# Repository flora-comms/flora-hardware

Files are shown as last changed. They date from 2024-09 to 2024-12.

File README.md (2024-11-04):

# flora-hardware

Repository for Petal Radio development.

## Root File Tree Overview

Overview of the root filetree.

### orders

Information related to hardware orders

### resources

Hardware resources, such as datasheets and diagrams.

### petal-v0_0

Hardware design files and assembly notes for Petal Radio V0.0.

### testing

Information related to hardware testing, including test code, checklists, and procedures.

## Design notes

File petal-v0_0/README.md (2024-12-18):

# petal-v0_0

Design, assembly, and testing files for Petal Radio v0.0

## File Tree Overview

Navigating this directory

### assembly

Assembly notes for Petal Radio v0.0. Includes notes on smt and th components, as well as the assembly checklist.

### enclosure

Enclosure files (.step, .stl, etc.)

### testing-results

Petal Radio v0.0 testing results. Testing procedures and templates can be found in the root testing folder.

### pcb

PCB Schematic and Altium files.

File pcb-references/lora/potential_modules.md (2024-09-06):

# Potential LoRa Modules

## WAVE

https://www.waveshare.com/wiki/Core1262-868M#Document

Vendors:
https://abra-electronics.com/wireless/lora/wave-20855.html

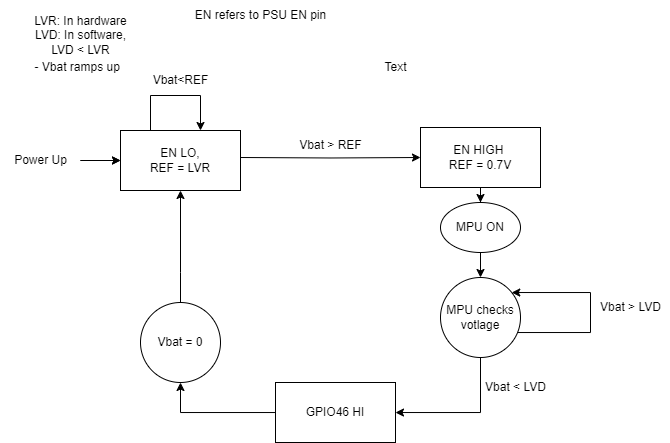
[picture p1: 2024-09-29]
pcb-references/power/LVD-state-machine.drawio.png

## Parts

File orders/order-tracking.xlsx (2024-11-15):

Project Supplies
Order # | Cost | Description | Date Submitted | Revision Date (?) | Date Approved | Received | Notes
1 | $108.85 | Wave LoRa Modules x 6 | 2024-09-16 | 2024-09-17 | 2024-09-17
2 | $22.15 | Jumpers and Justin's hogs x 2 | 2024-09-23 | n/a | 2024-09-23
3 | $210.07 | Petal v0.0 hardware order | 2024-10-14 | 2024-10-15 | 2024-10-15 | Friday,Octoder 18, 2024 | 47uF caps and 1k5 res were out of stock @ mouser, switched to kyocera caps and found res in stock on digikey
4 | $61.07 | Spare petal hardware and sd cards. Mouser + Amazon | 2024-11-04 | n/a | 2024-11-05 | Friday, October 8 and Tuesday October 12 | Amazon order came later than mouser
5 | $21.37 | IPEX to N and N to SMA RF connectors | 2024-11-11 | n/a | 2024-11-13 |  | Delayed… pushed back testing a week
 |  |  |  | n/a
 |  |  |  | n/a
 |  |  |  | n/a
PCB
Order # | Estimated Cost | Description | Date Submitted | Revision Date (?) | Date Approved | Notes
1 | $50.00 | Petal Radio v0.0 x 5 | 2024-10-14 | n/a | 2024-10-15 | JLC was unsure about the footprints for J8 and J7 because of the large solder mask opening. Told them to continue per the gerber -AH
 |  |  |  | n/a
 |  |  |  | n/a
 |  |  |  | n/a
 |  |  |  | n/a
 |  |  |  | n/a
 |  |  |  | n/a
 |  |  |  | n/a

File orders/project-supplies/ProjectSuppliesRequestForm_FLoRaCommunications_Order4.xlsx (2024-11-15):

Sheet: Mouser
 | Project Course Purchase Request Form. Post this to the #prep-room_orders channel when complete.
 | Project Name: |  |  | FLoRa Communications |  | Preferred Vendor: | Mouser | Student Name: | Aaron Huinink
 | Date: |  |  | 2024-11-15 |  |  |  | Student Email: | ahuinink@hotmail.ca
 |  |  |  |  |  |  | PLEASE FILL OUT ONE FORM PER PREFERRED VENDOR
 |  |  |  |  |  |  |  |  |  |  | FOR OFFICE USE ONLY
No. | Qty | QTY Rec. | Manufacturer Part # | Vendor Part # | Link to Part (URL) | Shipping From ( Country ) | Detailed Part Description | PCB Footprint | Unit Price ($CDN) | Extended Price | Notes for Office | Ordered | Delivered
1 | 20 |  | GCM21BR72A104KA37L | 81-GCM21BR72A104KA7L | https://www.mouser.ca/ProductDetail/Murata-Electronics/GCM21BR72A104KA37L?qs=aEuGZpxfbxU57i7kalIPTw%3D%3D | Canada | 100 nF Ceramic Capacitor - C1, C7, C8, C9, C12 (*C5&C6 removed from board) | 0805 | 0.113 | $2.2600
2 | 10 |  | GRM21BR60J226ME39L | 81-GRM21R60J226ME39L | https://www.mouser.ca/ProductDetail/Murata-Electronics/GRM21BR60J226ME39L?qs=DJY02EClX9n4vY1%2FNV53Qw%3D%3D | Canada | 22uF Ceramic Capacitor - C2, C11 | 0805 | 0.196 | $1.9600
3 | 10 |  | GCJ219R71C105KA01D | 81-GCJ219R71C105KA1D | https://www.mouser.ca/ProductDetail/Murata-Electronics/GCJ219R71C105KA01D?qs=TpyF2b7C1Q%252BYYZPnEdny3Q%3D%3D | Canada | 1uF Ceramic Capacitor - C3 | 0805 | 0.305 | $3.0500
4 | 10 |  | GRM21BR61E106KA73L | 81-GRM21BR61E106KA3L | https://www.mouser.ca/ProductDetail/Murata-Electronics/GRM21BR61E106KA73L?qs=Uw8ySfEHS7LOsCQEzvRcNg%3D%3D | Canada | 10uF Ceramic Capacitor - C10, C4, C18( *C18 Formerly 81-GRM21BR61E106MA3L) | 0805 | 0.157 | $1.5700
5
6 | 10 |  | 06033C104KAT2A | 581-06033C104KAT2A | https://www.mouser.ca/ProductDetail/KYOCERA-AVX/06033C104KAT2A?qs=gPDEucxdFwYuZhv3uXRdIw%3D%3D | Canada | 100 nF Ceramic Capacitor - C19, C16 (*C16 formerly 80-C0603C104Z4V) | 0603 | 0.145 | $1.4500
7 | 2 |  | GRM32EC80J107ME20L | 81-GRM32EC80J107ME0L | https://www.mouser.ca/ProductDetail/Murata-Electronics/GRM32EC80J107ME20L?qs=eCxWOFGThBZyUCwIudAIww%3D%3D | Canada | 100uF Ceramic Capacitor - C20 | 1210 | 2.58 | $5.1600
8 | 2 |  | TPSB475K035R0700 | 581-TPSB475K035R0700 | https://www.mouser.ca/ProductDetail/KYOCERA-AVX/TPSB475K035R0700?qs=vV7MX5mTKGOnhbxp1nxMNw%3D%3D | Canada | 4.7uF Tantalum Capacitor - C23 | 1210 | 1.07 | $2.1400
9 | 2 |  | ECH-U1H821JX5 | 667-ECH-U1H821JX5 | https://www.mouser.ca/ProductDetail/Panasonic/ECH-U1H821JX5?qs=nKUIxd1C0NJegDRFXgQx8Q%3D%3D | Canada | 820 pF Film Capacitor - C24 | 0805 | 0.522 | $1.0440
10 | 10 |  | ESD5B5.0ST1G | 863-ESD5B50ST1G | https://www.mouser.ca/ProductDetail/onsemi/ESD5B5.0ST1G?qs=bTNLGnZZEJg%2Fr8bn3zOMJw%3D%3D | Canada | SMT Protection Diode - D3, D4, D5 | SOD-523-2 | 0.193 | $1.9300
11 | 10 |  | ERJ-6ENF1002V | 667-ERJ-6ENF1002V | https://www.mouser.ca/ProductDetail/Panasonic/ERJ-6ENF1002V?qs=4WZYzuGhm5pfKPfuMiCO5g%3D%3D | Canada | SMT 10K Resistor - R1 | 0805 | 0.16 | $1.6000
12 | 10 |  | ERJ-6ENF4990V | 667-ERJ-6ENF4990V | https://www.mouser.ca/ProductDetail/Panasonic/ERJ-6ENF4990V?qs=tQNqqtTOejJ8SQeWozY0bw%3D%3D | Canada | SMT 499R - R2 | 0805 | 0.16 | $1.6000
13 | 15 |  | RNCP0805FTD100R | 708-RNCP0805FTD100R | https://www.mouser.ca/ProductDetail/SEI-Stackpole/RNCP0805FTD100R?qs=FESYatJ8odKa%252Bzqp4gsQrw%3D%3D | Canada | SMT 100R Resistor - R3, R4, R5 | 0805 | 0.032 | $0.4800
14 | 10 |  | RMCF0805FT100R | 708-RMCF0805FT100R | https://www.mouser.ca/ProductDetail/SEI-Stackpole/RMCF0805FT100R?qs=FESYatJ8odIZDyKRWKfVQQ%3D%3D | Canada | SMT Resistor 100Ohms -R7, R8 | 0805 | 0.019 | $0.1900
15 | 10 |  | CRCW0603100KFKEA | 71-CRCW0603-100K-E3 | https://www.mouser.ca/ProductDetail/Vishay-Dale/CRCW0603100KFKEA?qs=6dqgS%252BKntICWHMMdIzt5%2FQ%3D%3D | Canada | SMD resistor 100Kohms 1/10watt - R9 | 0603 | 0.145 | $1.4500
16 | 10 |  | RC0603FR-0730K9L | 603-RC0603FR-0730K9L | https://www.mouser.ca/ProductDetail/YAGEO/RC0603FR-0730K9L?qs=diQw95jMAeMZrPIXfOkmFA%3D%3D | Canada | SMD resistor 30.9 kOhms - R10 | 0603 | 0.145 | $1.4500
17 | 10 |  | ERJ-6RQFR47V | 667-ERJ-6RQFR47V | https://www.mouser.ca/ProductDetail/Panasonic/ERJ-6RQFR47V?qs=tQNqqtTOejIIgUosQKQ12Q%3D%3D | Canada | SMD resistor 0.47 Ohms - R11 | 0805 | 0.23 | $2.3000
18 | 10 |  | CRCW060310K0FKEA | 71-CRCW0603-10K-E3 | https://www.mouser.ca/ProductDetail/Vishay-Dale/CRCW060310K0FKEA?qs=pAO1Z172M84BVnhDjtnsoQ%3D%3D | Canada | Thick Film Resistor - SMD 1/10watt 10Kohms 1% -R12 | 0603 | 0.145 | $1.4500
19 | 20 |  | ERJ-6ENF2703V | 667-ERJ-6ENF2703V | https://www.mouser.ca/ProductDetail/Panasonic/ERJ-6ENF2703V?qs=50QC8w71jAsIUsFp0TwUKw%3D%3D | Canada | Thick Film Resistors - SMD 270Kohms - R13, R14, R18 | 0805 | 0.032 | $0.6400
20 | 10 |  | ERJ-6ENF1073V | 667-ERJ-6ENF1073V | https://www.mouser.ca/ProductDetail/Panasonic/ERJ-6ENF1073V?qs=JjxTDIFmKPR8KLEztkGZyw%3D%3D | Canada | Thick Film Resistors - SMD 0805 107Kohms - R15, R16, R22, R23 | 0805 | 0.026 | $0.2600
21 | 10 |  | ERJ-6ENF4023V | 667-ERJ-6ENF4023V | https://www.mouser.ca/ProductDetail/Panasonic/ERJ-6ENF4023V?qs=50QC8w71jAs%252BYzJfgzNd5w%3D%3D | Canada | Thick Film Resistors - SMD 0805 402Kohms - R17 | 0805 | 0.145 | $1.4500
22 | 10 |  | ERJ-6ENF5902V | 667-ERJ-6ENF5902V | https://www.mouser.ca/ProductDetail/Panasonic/ERJ-6ENF5902V?qs=50QC8w71jAsddX83LVzkRA%3D%3D | Canada | Thick Film Resistors - SMD 59Kohms - R19 | 0805 | 0.16 | $1.6000
23 | 10 |  | ERJ-6ENF1182V | 667-ERJ-6ENF1182V | https://www.mouser.ca/ProductDetail/Panasonic/ERJ-6ENF1182V?qs=JjxTDIFmKPQZscRXwQ1smA%3D%3D | Canada | Thick Film Resistors - SMD 0805 11.8Kohms - R20 | 0805 | 0.145 | $1.4500
24 | 10 |  | ERJ-6ENF4022V | 667-ERJ-6ENF4022V | https://www.mouser.ca/ProductDetail/Panasonic/ERJ-6ENF4022V?qs=tQNqqtTOejK24%252BpEKJjobQ%3D%3D | Canada | Thick Film Resistors - SMD 0805 40.2Kohms -R21 | 0805 | 0.16 | $1.6000
25 |  |  |  |  |  |  |  |  |  | $0.0000
26 |  |  |  |  |  |  |  |  |  | $0.0000
27 |  |  |  |  |  |  |  |  |  | $0.0000
28 |  |  |  |  |  |  |  |  |  | $0.0000
29 |  |  |  |  |  |  |  |  |  | $0.0000
30 |  |  |  |  |  |  |  |  |  | $0.0000
31 |  |  |  |  |  |  |  |  |  | $0.0000
32 |  |  |  |  |  |  |  |  |  | $0.0000
33 |  |  |  |  |  |  |  |  |  | $0.0000
34 |  |  |  |  |  |  |  |  |  | $0.0000
35 |  |  |  |  |  |  |  |  |  | $0.0000
36 |  |  |  |  |  |  |  |  |  | $0.0000
37 |  |  |  |  |  |  |  |  |  | $0.0000
38 |  |  |  |  |  |  |  |  |  | $0.0000
39 |  |  |  |  |  |  |  |  |  | $0.0000
40 |  |  |  |  |  |  |  |  |  | $0.0000
41 |  |  |  |  |  |  |  |  |  | $0.0000
42 |  |  |  |  |  |  |  |  |  | $0.0000
43 |  |  |  |  |  |  |  |  |  | $0.0000
44 |  |  |  |  |  |  |  |  |  | $0.0000
45 |  |  |  |  |  |  |  |  |  | $0.0000
46 |  |  |  |  |  |  |  |  |  | $0.0000
47 |  |  |  |  |  |  |  |  |  | $0.0000
48 |  |  |  |  |  |  |  |  |  | $0.0000
49 |  |  |  |  |  |  |  |  |  | $0.0000
50 |  |  |  |  |  |  |  |  |  | $0.0000
 |  |  |  |  |  |  |  | Total |  | $38.0840

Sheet: Amazon
 | Project Course Purchase Request Form. Post this to the #prep-room_orders channel when complete.
 | Project Name: |  |  | FLoRa Communications |  | Preferred Vendor: | Amazon | Student Name: | Aaron Huinink
 | Date: |  |  | 2024-11-15 |  |  |  | Student Email: | ahuinink@hotmail.ca
 |  |  |  |  |  |  | PLEASE FILL OUT ONE FORM PER PREFERRED VENDOR
 |  |  |  |  |  |  |  |  |  |  | FOR OFFICE USE ONLY
No. | Qty | QTY Rec. | Manufacturer Part # | Vendor Part # | Link to Part (URL) | Shipping From ( Country ) | Detailed Part Description | PCB Footprint | Unit Price ($CDN) | Extended Price | Notes for Office | Ordered | Delivered
1 | 1 |  | CDYW5pack | N/A | https://www.amazon.ca/Cloudisk-Memory-Adapter-Reader-TF-Black-5/dp/B0D2TBCBR4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 | Canada | 4 GB Micro SD Cards (5 Pack) | N/A | 22.99 | $22.9900
2 |  |  |  |  |  |  |  |  |  | $0.0000
3 |  |  |  |  |  |  |  |  |  | $0.0000
4 |  |  |  |  |  |  |  |  |  | $0.0000
5 |  |  |  |  |  |  |  |  |  | $0.0000
6 |  |  |  |  |  |  |  |  |  | $0.0000
7 |  |  |  |  |  |  |  |  |  | $0.0000
8 |  |  |  |  |  |  |  |  |  | $0.0000
9 |  |  |  |  |  |  |  |  |  | $0.0000
10 |  |  |  |  |  |  |  |  |  | $0.0000
11 |  |  |  |  |  |  |  |  |  | $0.0000
12 |  |  |  |  |  |  |  |  |  | $0.0000
13 |  |  |  |  |  |  |  |  |  | $0.0000
14 |  |  |  |  |  |  |  |  |  | $0.0000
15 |  |  |  |  |  |  |  |  |  | $0.0000
16 |  |  |  |  |  |  |  |  |  | $0.0000
17 |  |  |  |  |  |  |  |  |  | $0.0000
18 |  |  |  |  |  |  |  |  |  | $0.0000
19 |  |  |  |  |  |  |  |  |  | $0.0000
20 |  |  |  |  |  |  |  |  |  | $0.0000
21 |  |  |  |  |  |  |  |  |  | $0.0000
22 |  |  |  |  |  |  |  |  |  | $0.0000
23 |  |  |  |  |  |  |  |  |  | $0.0000
24 |  |  |  |  |  |  |  |  |  | $0.0000
25 |  |  |  |  |  |  |  |  |  | $0.0000
26 |  |  |  |  |  |  |  |  |  | $0.0000
27 |  |  |  |  |  |  |  |  |  | $0.0000
28 |  |  |  |  |  |  |  |  |  | $0.0000
29 |  |  |  |  |  |  |  |  |  | $0.0000
30 |  |  |  |  |  |  |  |  |  | $0.0000
31 |  |  |  |  |  |  |  |  |  | $0.0000
32 |  |  |  |  |  |  |  |  |  | $0.0000
33 |  |  |  |  |  |  |  |  |  | $0.0000
34 |  |  |  |  |  |  |  |  |  | $0.0000
35 |  |  |  |  |  |  |  |  |  | $0.0000
36 |  |  |  |  |  |  |  |  |  | $0.0000
37 |  |  |  |  |  |  |  |  |  | $0.0000
38 |  |  |  |  |  |  |  |  |  | $0.0000
39 |  |  |  |  |  |  |  |  |  | $0.0000
40 |  |  |  |  |  |  |  |  |  | $0.0000
41 |  |  |  |  |  |  |  |  |  | $0.0000
42 |  |  |  |  |  |  |  |  |  | $0.0000
43 |  |  |  |  |  |  |  |  |  | $0.0000
44 |  |  |  |  |  |  |  |  |  | $0.0000
45 |  |  |  |  |  |  |  |  |  | $0.0000
46 |  |  |  |  |  |  |  |  |  | $0.0000
47 |  |  |  |  |  |  |  |  |  | $0.0000
48 |  |  |  |  |  |  |  |  |  | $0.0000
49 |  |  |  |  |  |  |  |  |  | $0.0000
50 |  |  |  |  |  |  |  |  |  | $0.0000
 |  |  |  |  |  |  |  | Total |  | $22.9900

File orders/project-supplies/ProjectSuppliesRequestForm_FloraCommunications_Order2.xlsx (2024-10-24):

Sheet: Mouser
 | Project Course Purchase Request Form. Post this to the #prep-room_orders channel when complete.
 | Project Name: |  | FLoRa |  | Preferred Vendor: | Mouser | Student Name: | Tella Osler
 | Date: |  | 2024-10-14 |  |  |  | Student Email: | tella.osler@gmail.com
 |  |  |  |  |  | PLEASE FILL OUT ONE FORM PER PREFERRED VENDOR
 |  |  |  |  |  |  |  |  |  | FOR OFFICE USE ONLY
No. | Qty | Manufacturer Part # | Vendor Part # | Link to Part (URL) | Shipping From ( Country ) | Detailed Part Description | PCB Footprint | Unit Price ($CDN) | Extended Price | Notes for Office | Ordered | Delivered
1 | 2 | TPSM84203EAB | 595-TPSM84203EAB | https://www.mouser.ca/ProductDetail/Texas-Instruments/TPSM84203EAB?qs=EU6FO9ffTwdvD6IyQBtt5A%3D%3D | CAN | Non-Isolated DC/DC Converters 1.5A, 28V Input, 3.3V Output, TO-220 Power Module 3-SIP MODULE -40 to 125 | n/a | $9.61 | $9.61
2
3
4
5
6
7
8
9
10
11
12
13
14
15
16
17
18
19
20
21
22
23
24
25
26
27
28
29
30
31
32
33
34
35
36
37
38
39
40
41
42
43
44
45
46
47
48
49
50
 |  |  |  |  |  |  | Total |  | $9.6100

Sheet: Digikey
 | Project Course Purchase Request Form. Post this to the #prep-room_orders channel when complete.
 | Project Name: |  | FLoRa |  | Preferred Vendor: | Digikey | Student Name: | Tella Osler
 | Date: |  | 2024-09-23 |  |  |  | Student Email: | tella.osler@gmail.com
 |  |  |  |  |  | PLEASE FILL OUT ONE FORM PER PREFERRED VENDOR
 |  |  |  |  |  |  |  |  |  | FOR OFFICE USE ONLY
No. | Qty | Manufacturer Part # | Vendor Part # | Link to Part (URL) | Shipping From ( Country ) | Detailed Part Description | PCB Footprint | Unit Price ($CDN) | Extended Price | Notes for Office | Ordered | Delivered
1 | 50 | SPC02SYAN | S9001-ND | https://www.digikey.ca/en/products/detail/sullins-connector-solutions/spc02syan/76375 | Canada | 2 (1 x 2) Position Shunt Connector Black Closed Top 0.100" (2.54mm) Gold | n/a | $0.06 | $2.93

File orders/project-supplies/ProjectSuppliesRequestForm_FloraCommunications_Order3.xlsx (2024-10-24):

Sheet: Mouser
 | Project Course Purchase Request Form. Post this to the #prep-room_orders channel when complete.
 | Project Name: |  |  | FLoRa Communications |  | Preferred Vendor: | Mouser | Student Name: | Aaron Huinink
 | Date: |  |  | 2024-10-18 |  |  |  | Student Email: | ahuinink@hotmail.ca
 |  |  |  |  |  |  | PLEASE FILL OUT ONE FORM PER PREFERRED VENDOR
 |  |  |  |  |  |  |  |  |  |  | FOR OFFICE USE ONLY
No. | Qty | QTY Rec. | Manufacturer Part # | Vendor Part # | Link to Part (URL) | Shipping From ( Country ) | Detailed Part Description | PCB Footprint | Unit Price ($CDN) | Extended Price | Notes for Office | Ordered | Delivered
1 | 35 | 35 | GCM21BR72A104KA37L | 81-GCM21BR72A104KA7L | https://www.mouser.ca/ProductDetail/Murata-Electronics/GCM21BR72A104KA37L?qs=aEuGZpxfbxU57i7kalIPTw%3D%3D | Canada | 100 nF Ceramic Capacitor - C1, C5, C6, C7, C8, C9, C12 | 0805 | 0.113 | $3.9550
2 | 10 | 10 | GRM21BR60J226ME39L | 81-GRM21R60J226ME39L | https://www.mouser.ca/ProductDetail/Murata-Electronics/GRM21BR60J226ME39L?qs=DJY02EClX9n4vY1%2FNV53Qw%3D%3D | Canada | 22uF Ceramic Capacitor - C2, C11 | 0805 | 0.196 | $1.9600
3 | 5 | 5 | GCJ219R71C105KA01D | 81-GCJ219R71C105KA1D | https://www.mouser.ca/ProductDetail/Murata-Electronics/GCJ219R71C105KA01D?qs=TpyF2b7C1Q%252BYYZPnEdny3Q%3D%3D | Canada | 1uF Ceramic Capacitor - C3 | 0805 | 0.305 | $1.5250
4 | 10 | 10 | GRM21BR61E106KA73L | 81-GRM21BR61E106KA3L | https://www.mouser.ca/ProductDetail/Murata-Electronics/GRM21BR61E106KA73L?qs=Uw8ySfEHS7LOsCQEzvRcNg%3D%3D | Canada | 10uF Ceramic Capacitor - C10, C4 | 0805 | 0.157 | $1.5700
5 | 10 | 10 | GRM21BR61E106KA73L | 810-C3216X5R1E476M | https://www.mouser.ca/ProductDetail/TDK/C3216X5R1E476M160AC?qs=NRhsANhppD%252BqapdVvBvu4Q%3D%3D | Canada | 47 uF Capacitor - C13,C14 | 1206 | 0.813 | $8.1300
6 | 5 | 5 | GRT31CR61H106KE01L | 81-GRT31CR61H106KE1L | https://www.mouser.ca/ProductDetail/Murata-Electronics/GRT31CR61H106KE01L?qs=drgMNd%252BkGPOfk81gMUj0ow%3D%3D | Canada | 10 uF Capacitor - C15 | 1206 | 0.899 | $4.4950
7 | 5 | 5 | C0603C104Z4VACTU | 80-C0603C104Z4V | https://www.mouser.ca/ProductDetail/KEMET/C0603C104Z4VACTU?qs=t9q%2F2xDdjt80hHjNGtEgzg%3D%3D | Canada | 100 nF Ceramic Capacitor - C16 | 0603 | 0.145 | $0.7250
8 | 15 | 15 | GRM32ER61E226KE15L | 81-GRM32ER61E226KE15 | https://www.mouser.ca/ProductDetail/Murata-Electronics/GRM32ER61E226KE15L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 | Canada | 22uF Ceramic Capacitor - C17,C20,C21 | 1210 | 2.04 | $30.6000
9 | 5 | 5 | GRM21BR61E106MA73L | 81-GRM21BR61E106MA3L | https://www.mouser.ca/ProductDetail/Murata-Electronics/GRM21BR61E106MA73L?qs=2W5sgKM%2F371odLMyCilkag%3D%3D | Canada | 10 uF Capacitor - C18 | 0805 | 0.29 | $1.4500 |  |  |  | 5
10 | 5 | 5 | 06033C104KAT2A | 581-06033C104KAT2A | https://www.mouser.ca/ProductDetail/KYOCERA-AVX/06033C104KAT2A?qs=gPDEucxdFwYuZhv3uXRdIw%3D%3D | Canada | 100 nF Ceramic Capacitor - C19 | 0603 | 0.145 | $0.7250
11 | 5 | 5 | GRM32EC80J107ME20L | 81-GRM32EC80J107ME0L | https://www.mouser.ca/ProductDetail/Murata-Electronics/GRM32EC80J107ME20L?qs=eCxWOFGThBZyUCwIudAIww%3D%3D | Canada | 100uF Ceramic Capacitor - C20 | 1210 | 2.58 | $12.9000
12 | 5 | 5 | TPSB475K035R0700 | 581-TPSB475K035R0700 | https://www.mouser.ca/ProductDetail/KYOCERA-AVX/TPSB475K035R0700?qs=vV7MX5mTKGOnhbxp1nxMNw%3D%3D | Canada | 4.7uF Tantalum Capacitor - C23 | 1210 | 1.07 | $5.3500
13 | 5 | 5 | ECH-U1H821JX5 | 667-ECH-U1H821JX5 | https://www.mouser.ca/ProductDetail/Panasonic/ECH-U1H821JX5?qs=nKUIxd1C0NJegDRFXgQx8Q%3D%3D | Canada | 820 pF Film Capacitor - C24 | 0805 | 0.522 | $2.6100
14 | 10 | 10 | 1N5819HW-7-F | 621-1N5819HW-F | https://www.mouser.ca/ProductDetail/Diodes-Incorporated/1N5819HW-7-F?qs=NQ47qNm99eDyWTEd07miYA%3D%3D | Canada | SMT Schottky diode - D1, D2 | SOD-123-2 | 0.247 | $2.4700
15 | 5 | 5 | 150505M173300 | 710-150505M173300 | https://www.mouser.ca/ProductDetail/Wurth-Elektronik/150505M173300?qs=fAHHVMwC%252Bbi%2FURn4Qu0%2FAA%3D%3D | Canada | SMT RGB LED - D6 | Custom SMT | 0.914 | $4.5700
16 | 15 | 15 | ESD5B5.0ST1G | 863-ESD5B50ST1G | https://www.mouser.ca/ProductDetail/onsemi/ESD5B5.0ST1G?qs=bTNLGnZZEJg%2Fr8bn3zOMJw%3D%3D | Canada | SMT Protection Diode - D3, D4, D5 | SOD-523-2 | 0.193 | $2.8950
17 | 10 | 10 | 1729128 | 651-1729128 | https://www.mouser.ca/ProductDetail/Phoenix-Contact/1729128?qs=GFUSqQMLmmnCBVBY3dts9w%3D%3D | Canada | 2 position screw terminal - J2, J11 | THT | 1.3 | $13.0000
18 | 5 | 5 | 10103594-0001LF | 649-10103594-0001LF | https://www.mouser.ca/ProductDetail/Amphenol-FCI/10103594-0001LF?qs=EnLMdcWnKABYZwdMsmC%2Fag%3D%3D | Canada | SMT Micro USB Port - J3 | Custom SMT | 1.15 | $5.7500
19 | 5 | 5 | MEM2061-01-188-00-A | 640-MEM20610118800A | https://www.mouser.ca/ProductDetail/GCT/MEM2061-01-188-00-A?qs=KUoIvG%2F9IlYc25USp0M1eQ%3D%3D | Canada | SMT SD Card reader - J5 | Custom SMT | 1.78 | $8.9000
20 | 5 | 5 | 74479299222 | 710-74479299222 | https://www.mouser.ca/ProductDetail/Wurth-Elektronik/74479299222?qs=16w8nSHsg3tcdL6pYOiu3w%3D%3D | Canada | SMT Power Inductor - L1 | 1210 | 1.39 | $6.9500
21 | 5 | 5 | IHLP3232DZER4R7M1 | 70-IHLP3232DZER4R7M1 | https://www.mouser.ca/ProductDetail/Vishay-Dale/IHLP3232DZER4R7M11?qs=Nbmv7C3%2FzlBkjG9ees3Knw%3D%3D | Canada | SMT Power Inductor - L2 | 3232 | 1.83 | $9.1500
22 | 5 | 5 | ERJ-6ENF1002V | 667-ERJ-6ENF1002V | https://www.mouser.ca/ProductDetail/Panasonic/ERJ-6ENF1002V?qs=4WZYzuGhm5pfKPfuMiCO5g%3D%3D | Canada | SMT 10K Resistor - R1 | 0805 | 0.16 | $0.8000
23 | 5 | 5 | ERJ-6ENF4990V | 667-ERJ-6ENF4990V | https://www.mouser.ca/ProductDetail/Panasonic/ERJ-6ENF4990V?qs=tQNqqtTOejJ8SQeWozY0bw%3D%3D | Canada | SMT 499R - R2 | 0805 | 0.16 | $0.8000
24 | 15 | 15 | RNCP0805FTD100R | 708-RNCP0805FTD100R | https://www.mouser.ca/ProductDetail/SEI-Stackpole/RNCP0805FTD100R?qs=FESYatJ8odKa%252Bzqp4gsQrw%3D%3D | Canada | SMT 100R Resistor - R3, R4, R5 | 0805 | 0.032 | $0.4800
25 | 5 | 5 | ERJ-6ENF1501V | 667-ERJ-6ENF1501V | https://www.mouser.ca/ProductDetail/Panasonic/ERJ-6ENF1501V?qs=4WZYzuGhm5qa4PPEzdMS5A%3D%3D | Canada | SMT Resistor 1.5Kohms- R6 | 0805 | 0.16 | $0.8000
26 | 10 | 10 | RMCF0805FT100R | 708-RMCF0805FT100R | https://www.mouser.ca/ProductDetail/SEI-Stackpole/RMCF0805FT100R?qs=FESYatJ8odIZDyKRWKfVQQ%3D%3D | Canada | SMT Resistor 100Ohms -R7, R8 | 0805 | 0.019 | $0.1900
27 | 5 | 5 | CRCW0603100KFKEA | 71-CRCW0603-100K-E3 | https://www.mouser.ca/ProductDetail/Vishay-Dale/CRCW0603100KFKEA?qs=6dqgS%252BKntICWHMMdIzt5%2FQ%3D%3D | Canada | SMD resistor 100Kohms 1/10watt - R9 | 0603 | 0.145 | $0.7250
28 | 5 | 5 | RC0603FR-0730K9L | 603-RC0603FR-0730K9L | https://www.mouser.ca/ProductDetail/YAGEO/RC0603FR-0730K9L?qs=diQw95jMAeMZrPIXfOkmFA%3D%3D | Canada | SMD resistor 30.9 kOhms - R10 | 0603 | 0.145 | $0.7250
29 | 5 | 5 | ERJ-6RQFR47V | 667-ERJ-6RQFR47V | https://www.mouser.com/ProductDetail/Panasonic/ERJ-6RQFR47V?qs=tQNqqtTOejIIgUosQKQ12Q%3D%3D | Canada | SMD resistor 0.47 Ohms - R11 | 0805 | 0.23 | $1.1500
30 | 5 | 5 | CRCW060310K0FKEA | 71-CRCW0603-10K-E3 | https://www.mouser.ca/ProductDetail/Vishay-Dale/CRCW060310K0FKEA?qs=pAO1Z172M84BVnhDjtnsoQ%3D%3D | Canada | Thick Film Resistor - SMD 1/10watt 10Kohms 1% -R12 | 0603 | 0.145 | $0.7250
31 | 15 | 15 | ERJ-6ENF2703V | 667-ERJ-6ENF2703V | https://www.mouser.ca/ProductDetail/Panasonic/ERJ-6ENF2703V?qs=50QC8w71jAsIUsFp0TwUKw%3D%3D | Canada | Thick Film Resistors - SMD 270Kohms - R13, R14, R18 | 0805 | 0.032 | $0.4800
32 | 20 | 20 | ERJ-6ENF1073V | 667-ERJ-6ENF1073V | https://www.mouser.ca/ProductDetail/Panasonic/ERJ-6ENF1073V?qs=JjxTDIFmKPR8KLEztkGZyw%3D%3D | Canada | Thick Film Resistors - SMD 0805 107Kohms - R15, R16, R22, R23 | 0805 | 0.026 | $0.5200
33 | 5 | 5 | ERJ-6ENF4023V | 667-ERJ-6ENF4023V | https://www.mouser.ca/ProductDetail/Panasonic/ERJ-6ENF4023V?qs=50QC8w71jAs%252BYzJfgzNd5w%3D%3D | Canada | Thick Film Resistors - SMD 0805 402Kohms - R17 | 0805 | 0.145 | $0.7250
34 | 5 | 5 | ERJ-6ENF5902V | 667-ERJ-6ENF5902V | https://www.mouser.ca/ProductDetail/Panasonic/ERJ-6ENF5902V?qs=50QC8w71jAsddX83LVzkRA%3D%3D | Canada | Thick Film Resistors - SMD 59Kohms - R19 | 0805 | 0.16 | $0.8000
35 | 5 | 5 | ERJ-6ENF1182V | 667-ERJ-6ENF1182V | https://www.mouser.ca/ProductDetail/Panasonic/ERJ-6ENF1182V?qs=JjxTDIFmKPQZscRXwQ1smA%3D%3D | Canada | Thick Film Resistors - SMD 0805 11.8Kohms - R20 | 0805 | 0.145 | $0.7250
36 | 5 | 5 | ERJ-6ENF4022V | 667-ERJ-6ENF4022V | https://www.mouser.ca/ProductDetail/Panasonic/ERJ-6ENF4022V?qs=tQNqqtTOejK24%252BpEKJjobQ%3D%3D | Canada | Thick Film Resistors - SMD 0805 40.2Kohms -R21 | 0805 | 0.16 | $0.8000
37 | 15 | 15 | PTS526 SK15 SMTR2 LFS | 611-PTS526SK15SMR2L | https://www.mouser.ca/ProductDetail/CK/PTS526-SK15-SMTR2-LFS?qs=UXgszm6BlbF5Ezp94JAQtw%3D%3D | Canada | Tactile Switches 50mA 12VDC - SW1, SW2, SW3 | SMT | 0.186 | $2.7900
38 | 5 | 5 | ESP32-S3-MINI-1-N8 | 356-ESP32-S3-MINI1N8 | https://www.mouser.ca/ProductDetail/Espressif-Systems/ESP32-S3-MINI-1-N8?qs=XAiT9M5g4x82rl6F%2FIYUQg%3D%3D | Canada | Multiprotocol Modules SMD module, ESP32-S3FN8, 8 MB SPI flash, PCB antenna -U1 | SMT | 4.5 | $22.5000
39 | 5 | 5 | TPS62933PDRLR | 595-TPS62933PDRLR | https://www.mouser.ca/ProductDetail/Texas-Instruments/TPS62933PDRLR?qs=vvQtp7zwQdPCuPvhGs%2FYxA%3D%3D | Canada | Switching Voltage Regulators 3.8-V to 30-V, 3-A, 200-kHz to 2.2-MHz, low-IQ synchronous buck converter in SOT-583 8-SOT-5X3 -40 to 150 | SOT-583-8 | 1.65 | $8.2500
 |  |  |  |  |  |  |  | Total |  | $173.6650
 |  |  | 5

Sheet: Digikey
 | Project Course Purchase Request Form. Post this to the #prep-room_orders channel when complete.
 | Project Name: |  |  | FLoRa Communications |  | Preferred Vendor: | Digikey | Student Name: | Aaron Huinink
 | Date: |  |  | 2024-10-18 |  |  |  | Student Email: | ahuinink@hotmail.ca
 |  |  |  |  |  |  | PLEASE FILL OUT ONE FORM PER PREFERRED VENDOR
 |  |  |  |  |  |  |  |  |  |  | FOR OFFICE USE ONLY
No. | Qty | Qty Rec, | Manufacturer Part # | Vendor Part # | Link to Part (URL) | Shipping From ( Country ) | Detailed Part Description | PCB Footprint | Unit Price ($CDN) | Extended Price | Notes for Office | Ordered | Delivered
1 | 10 | 10 | 61300621121 | 732-5295-ND | https://www.digikey.ca/en/products/detail/würth-elektronik/61300621121/4846835?s=N4IgTCBcDaIGwEYDMAGFcwIZkBdAvkA | Canada | 6 Pin 2 Row Male Header - P1, P2 | THT | $0.7030 | $7.0300
2 | 10 | 10 | PPTC041LFBN-RC | S7002-ND | https://www.digikey.ca/en/products/detail/PPTC041LFBN-RC/S7002-ND/810144?curr=usd | Canada | 4 Pin female header - J1, J4 | THT | $0.6030 | $6.0300
3 | 5 | 5 | 20021321-00010C4LF | 609-3706-1-ND | https://www.digikey.ca/en/products/detail/amphenol-cs-fci/20021321-00010C4LF/2209058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 | Canada | 2x5 1.27mm pitch female header - J6 | SMT | $1.9600 | $9.8000
4 | 10 | 10 | 20021311-00006T4LF | 609-3752-ND | https://www.digikey.ca/en/products/detail/amphenol-cs-fci/20021311-00006T4LF/2209073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 | Canada | 2x3 1.27mm pitch female header - J7, J8 | THT | $0.8890 | $8.8900
5 | 10 | 10 | PREC003SAAN-RC | S1012EC-03-ND | https://www.digikey.ca/en/products/detail/PREC003SAAN-RC/S1012EC-03-ND/2774851?curr=usd | Canada | 1x3 2.54mm pitch male header - J9, J10 | THT | $0.4660 | $4.6600
 |  |  |  |  |  |  |  | Total |  | $36.4100
 |  |  |  | 5

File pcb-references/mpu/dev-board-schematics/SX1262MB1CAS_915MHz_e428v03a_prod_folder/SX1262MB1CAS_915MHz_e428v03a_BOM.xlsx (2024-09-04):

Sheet: SX1262MB1CAS
 |  |  | SX1262MB1CAS RF Module - 4-Layers 915MHz BOM |  |  | BOM # V1a
 |  |  |  |  |  | SCH # e428v03a
 |  |  | 2023-09-25 | EMr | Version e428v03a | PCB # e428v03a
RefDes | MPN | Geom | Value | Qty | Description | Manufacturer
U1 | SX1262IMLTRT | VQFN24 4x4mm | SX1262 | 1 | 150MHz to 960MHz Low Power Long Range Transceiver | Semtech
U2 | PE4259 | SC70-6 | PE4259 | 1 | SPDT High Power UltraCMOS 10 MHz - 3.0 GHz RF Switch | Peregrine
Resistors
R2 | CRCW06030000Z0EAHP | 0603 | 0R | 1 | Thick Film Resistor ±1%, 1/4W | Vishay/Dale
R3 | CRCW0402100RFKED | 0402 | 100R | 1 | Thick Film Resistor ±1%, 1/16W | Vishay/Dale
R4 | CRCW0402100RFKED | 0402 | 100R | 1 | Thick Film Resistor ±1%, 1/16W | Vishay/Dale
R12 | CRCW04020000Z0ED | 0402 | 0R | 1 | Thick Film Resistor ±1%, 1/16W | Vishay/Dale
R13 | CRCW040210K0FKED | 0402 | 10k | 1 | Thick Film Resistor ±1%, 1/16W | Vishay/Dale
R15 | CRCW0402330RFKED | 0402 | 330R | 1 | Thick Film Resistor ±1%, 1/16W | Vishay/Dale
R16 | CRCW0402330RFKED | 0402 | 330R | 1 | Thick Film Resistor ±1%, 1/16W | Vishay/Dale
R915 | CRCW04020000Z0ED | 0402 | 0R | 1 | Thick Film Resistor ±1%, 1/16W | Vishay/Dale
SX1262 | CRCW040210K0FKED | 0402 | 10k | 1 | Thick Film Resistor ±1%, 1/16W | Vishay/Dale
FR1 | CRCW040210K0FKED | 0402 | 10k | 1 | Thick Film Resistor ±1%, 1/16W | Vishay/Dale
XTAL | CRCW04020000Z0ED | 0402 | 0R | 1 | Thick Film Resistor ±1%, 1/16W | Vishay/Dale
Capacitors
C1 | GRM155R71C473KA01D | 0402 | 47nF | 1 | Multilayer ceramic capacitors X7R ±10%, 16V | Murata
C2 | GJM1555C1H470JB01D | 0402 | 47pF | 1 | Multilayer ceramic capacitors C0G ±5%, 50V | Murata
C4 | GJM1555C1H3R0BB01D | 0402 | 3.0pF | 1 | Multilayer ceramic capacitors C0G ±0.1pF, 50V | Murata
C5 | GJM1555C1H5R6CB01D | 0402 | 5.6pF | 1 | Multilayer ceramic capacitors C0G ±0.25pF, 50V | Murata
C6 | GJM1555C1H390JB01D | 0402 | 39pF | 1 | Multilayer ceramic capacitors C0G ±5%, 50V | Murata
C7 | GJM1555C1H1R8BB01D | 0402 | 1.8pF | 1 | Multilayer ceramic capacitors C0G ±0.1pF, 50V | Murata
C8 | GJM1555C1H390JB01D | 0402 | 39pF | 1 | Multilayer ceramic capacitors C0G ±5%, 50V | Murata
C9 | GJM1555C1H3R3BB01D | 0402 | 3.3pF | 1 | Multilayer ceramic capacitors C0G ±0.1pF, 50V | Murata
C10 | GJM1555C1H3R3BB01D | 0402 | 3.3pF | 1 | Multilayer ceramic capacitors C0G ±0.1pF, 50V | Murata
C11 | GJM1555C1H2R4BB01D | 0402 | 2.4pF | 1 | Multilayer ceramic capacitors C0G ±0.1pF, 50V | Murata
C12 | GJM1555C1H1R8BB01D | 0402 | 1.8pF | 1 | Multilayer ceramic capacitors C0G ±0.1pF, 50V | Murata
C14 | GRM155R72A102KA01D | 0402 | 1nF | 1 | Multilayer ceramic capacitors X7R ±10%, 100V | Murata
C15 | GRM155R72A102KA01D | 0402 | 1nF | 1 | Multilayer ceramic capacitors X7R ±10%, 100V | Murata
C16 | GRM155R61C105KA12D | 0402 | 1uF | 1 | Multilayer ceramic capacitors X5R ±10%, 16V | Murata
C17 | GRM155R71A474KE01D | 0402 | 470nF | 1 | Multilayer ceramic capacitors X7R ±10%, 10V | Murata
C18 | GRM155R71H104KE14D | 0402 | 100nF | 1 | Multilayer ceramic capacitors X7R ±10%, 50V | Murata
C20 | GRM155R61C105KA12D | 0402 (0603) | 1uF | 1 | Multilayer ceramic capacitors X5R ±10%, 16V | Murata
C21 | GRM155R61C105KA12D | 0402 (0603) | 1uF | 1 | Multilayer ceramic capacitors X5R ±10%, 16V | Murata
C22 | GRM188Z71A106KA73D | 0603 (0805) | 10uF | 1 | Multilayer ceramic capacitors X7R ±10%, 10V | Murata
C23 | GRM155R71C104KA88D | 0402 | 100nF | 1 | Multilayer ceramic capacitors X7R ±10%, 16V | Murata
C24 | GRM155R61C105KA12D | 0402 (0603) | 1uF | 1 | Multilayer ceramic capacitors X5R ±10%, 16V | Murata
C26 | GRM188Z71A106KA73D | 0603 (0805) | 10uF | 1 | Multilayer ceramic capacitors X7R ±10%, 10V | Murata
Inductors & Ferrites
L1 | LQW15AN47NJ00D | 0402 | 47nH | 1 | Wirewound Inductor ±5% | Murata
L2 | CRCW04020000Z0ED | 0402 | 0R | 1 | Thick Film Resistor ±1%, 1/16W | Vishay/Dale
L3 | LQW15AN2N5C00D | 0402 | 2.5nH | 1 | Wirewound Inductor ±0.2nH | Murata
L4 | LQW15AN4N7C00D | 0402 | 4.7nH | 1 | Wirewound Inductor ±0.2nH | Murata
L5 | LQW15AN9N1H00D | 0402 | 9.1nH | 1 | Wirewound Inductor ±3% | Murata
L6 | LQW15AN15NH00D | 0402 | 15nH | 1 | Wirewound Inductor ±3% | Murata
L7 | MLZ2012M150W | 0805 | 15uH | 1 | MLZ2012 Multilayer Shielded Inductor ±20% (populated) | TDK
or | MLZ1608N100LT000 | 0603 (0805) | 10uH | - | MLZ1608 Multilayer Shielded Inductor ±20% (recommended for new design) | TDK
or | MLZ1608N150LT000 | 0603 (0805) | 15uH | - | MLZ1608 Multilayer Shielded Inductor ±20% (recommended for new design) | TDK
LEDs and Diodes
Rx | LTST-C193KGKT-5A | SMT 1.6x0.8mm | GREEN | 1 | SMD LED 20mA or equivalent LED type | Lite ON
Tx | LTST-C193KRKT-5A | SMT 1.6x0.8mm | RED | 1 | SMD LED 20mA or equivalent LED type | Lite ON
Crystal & TCXO
Q1 | EXS00A-CS06465 | NX2016SA 2.0x1.6mm | 32.000MHz | 1 | Crystal unit NDK; Tol. ±10ppm, Cload=10pF, G-Senstivity=2ppb/G max | NDK
or | FTR5123-B0 | QESM09 2.0x1.6mm | 32.000MHz | - | Crystal unit Rakon; Tol. ±10ppm, Cload=10pF, G-Senstivity=2ppb/G max | Rakon
Connectors and others (or P/N equivalent)
RFIO | 142-0701-841 | SMA End Launch | 50 Ohms | 1 | SMA End launch jack receptacle for PCB mount | Cinch Connectivity Sol Johnson
J1 | 68000-108HLF | Header 1x8 | 8 pins | 1 | 8 Pins - Through hole single row male connector, Bottom side | FCI
J2 | 68000-110HLF | Header 1x10 | 10 pins | 1 | 10 Pins - Through hole single row male connector, Bottom side | FCI
J3 | 68000-108HLF | Header 1x8 | 8 pins | 1 | 8 Pins - Through hole single row male connector, Bottom side | FCI
J4 | 68000-106HLF | Header 1x6 | 6 pins | 1 | 6 Pins - Through hole single row male connector, Bottom side | FCI
J1_DISP | 75915-308LF | Receptacle 1x8 | 8 pins | 1 | 8 Pins - Through hole single row female receptacle, Top side | FCI
J2_DISP | 75915-310LF | Receptacle 1x10 | 10 pins | 1 | 10 Pins - Through hole single row female receptacle, Top side | FCI
J3_DISP | 75915-308LF | Receptacle 1x8 | 8 pins | 1 | 8 Pins - Through hole single row female receptacle, Top side | FCI
J4_DISP | 75915-306LF | Receptacle 1x6 | 6 pins | 1 | 6 Pins - Through hole single row female receptacle, Top side | FCI
VDD_RADIO | 68000-102HLF | Bridge 2p 2.54mm | 2 pins | 1 | 2 Pins - Through hole single row male connector, Top side | FCI
Additional components
- | M7566-05 | Jumper 2.54mm | - | 1 | Red Jumper Socket 2.54mm on VDD_RADIO for DC supply or equivalent | Harwin
- | BMI-S-209-F | Shield | - | 0 | Standard Surface Mount Shield in two parts with BMI-S-209-C cover (optional) | Laird Technologies
Remarks: components not listed in the BOM or 0 quantity, are not populated on the module.
It is recommended to use Semtech TVS diode model RClamp2451ZA placed close to the antenna connectors, to protect sensitive RF ports from damage or latch-up due to ESD, EFT, and EOS.
Murata GRM15 Multilayer ceramic capacitors series with values ≤ 47pF were replaced from previous BOM to new GJM15 series, as replacement with same capacitance value, voltage rating and tolerance.
GRM15 series ≤ 47pF are not recommended for new designs according to Murata.

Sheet: Release
 |  | SX1262MB1CAS RF Module - 4-Layers 915MHz BOM |  |  |  | BOM # V1a
 |  |  |  |  |  | SCH # e428v03a
 |  | 2023-09-25 | EMr | Version e428v03a |  | PCB # e428v03a
Release history
Version | Change notes |  |  |  | By
pcb_e428v03a | Based on PCB_E407V0xA version - SX1262 module - 4-layers with thermal reliefs |  |  |  | EMr
 | Updated BOM @915MHz
 | Updated Part Number and comment only, removed shield - 12.03.18 |  |  |  | EMr
 | Updated obsolete P/N for large capacitor values (>1.0uF) |  |  |  | EMr
 | Updated GJM capacitor type |  |  |  | 2023-09-25

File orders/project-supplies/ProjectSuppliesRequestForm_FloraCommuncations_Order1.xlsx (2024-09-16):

 | Project Course Purchase Request Form. Post this to the #prep-room_orders channel when complete.
 | Project Name: |  | FLoRa Communications |  | Preferred Vendor: | waveshare | Student Name: | Cameron Gillingham
 | Date: |  | 2024-09-16 |  |  |  | Student Email: | cameron.gillingham1@gmail.com
 |  |  |  |  |  | PLEASE FILL OUT ONE FORM PER PREFERRED VENDOR
 |  |  |  |  |  |  |  |  |  | FOR OFFICE USE ONLY
No. | Qty | Manufacturer Part # | Vendor Part # | Link to Part (URL) | Shipping From ( Country ) | Detailed Part Description | PCB Footprint | Unit Price ($CDN) | Extended Price | Notes for Office | Ordered | Delivered
1 | 6 | core1262-HF | 20855 | https://www.waveshare.com/core1262-868m.htm?sku=20855 | China | Core1262 LF/HF LoRa Module, SX1262 chip, Long-Range Communication, Anti-Interference, Suitable for Sub-GHz band | SMT | $10.8500 | $65.1000
2
3
4
5
6
7
8
9
10
11
12
13
14
15
16
17
18
19
20
21
22
23
24
25
26
27
28
29
30
31
32
33
34
35
36
37
38
39
40
41
42
43
44
45
46
47
48
49
50
 |  |  |  |  |  |  | Total |  | $65.1000

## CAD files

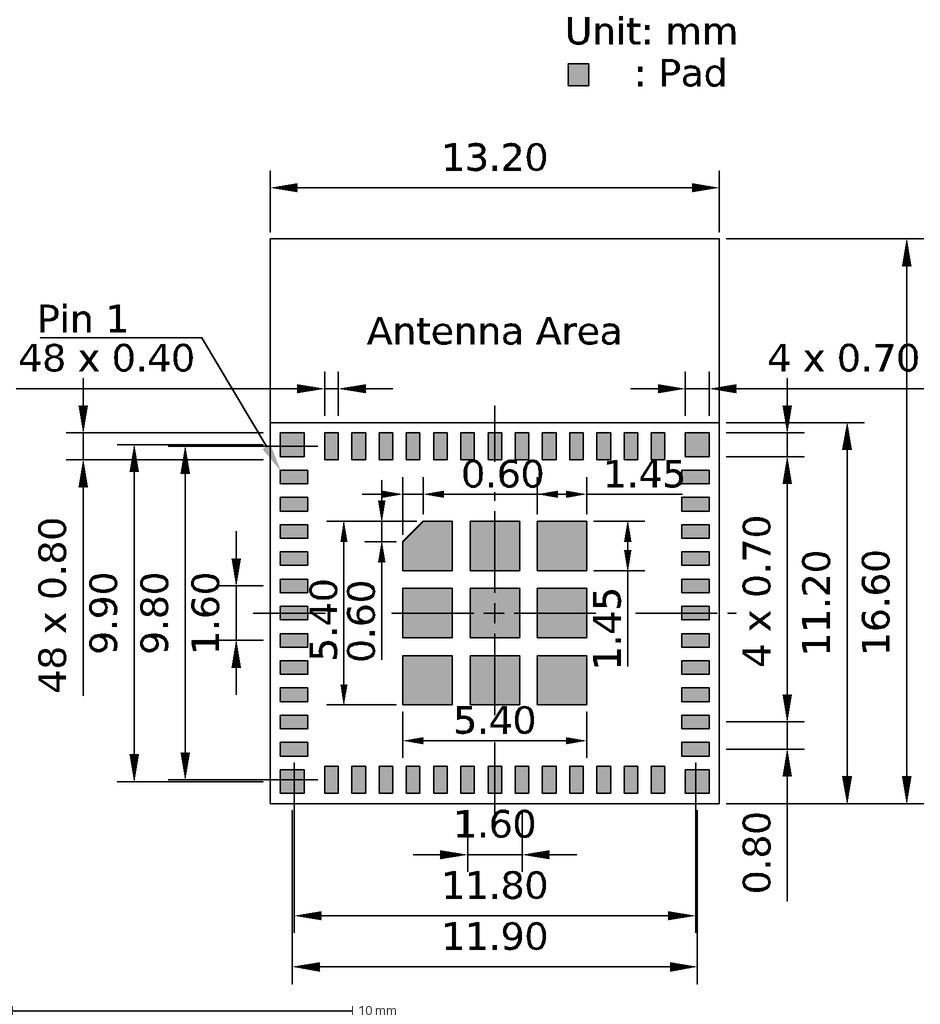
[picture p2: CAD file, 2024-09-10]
pcb-references/mpu/dev-board-schematics/ESP32-C6-Module/ESP32-C6-MINI-1 PCB Footprint.dxf
1.60
Antenna Area
Pin 1
11.20
0.60
9.90
5.40
11.90
13.20
16.60
1.45
11.80
9.80
Unit: mm
: Pad
48 x 0.40
48 x 0.80
4 x 0.70
0.80

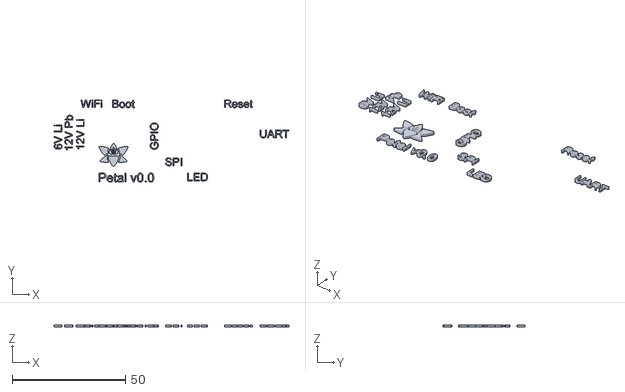
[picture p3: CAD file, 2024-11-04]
petal-v0_0/enclosure/inlay.stl
103.6 x 36.3 x 1.00

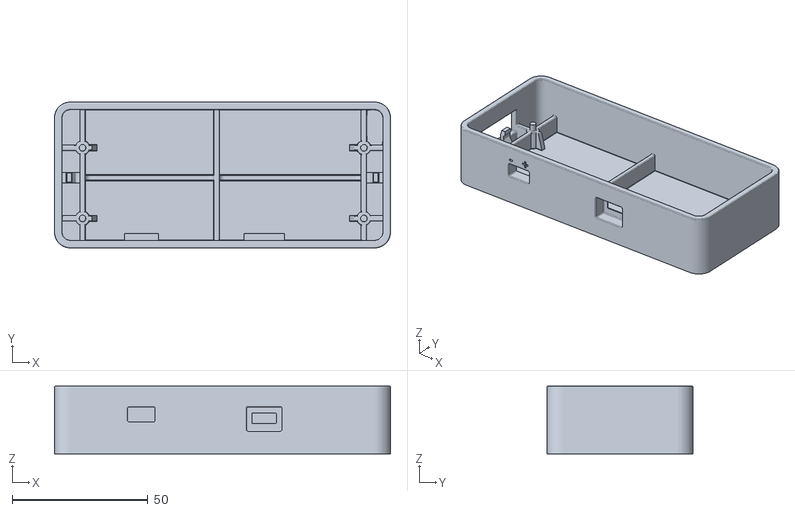
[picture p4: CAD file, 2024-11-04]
petal-v0_0/enclosure/base.stl
123.6 x 53.7 x 25.0

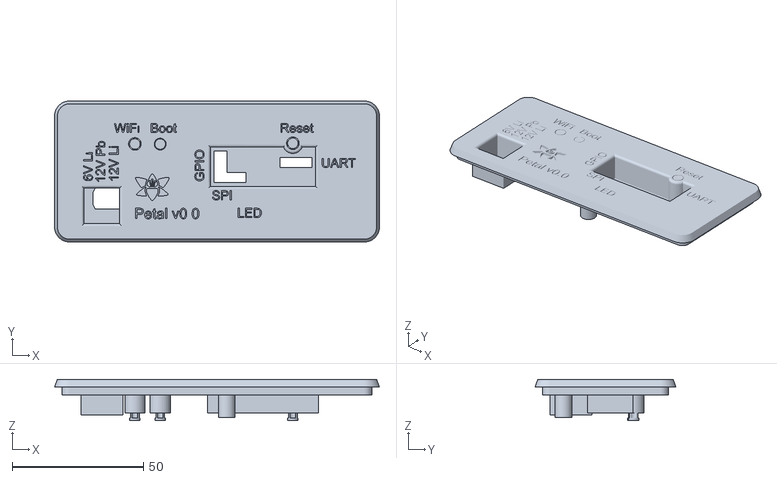
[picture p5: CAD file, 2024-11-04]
petal-v0_0/enclosure/lid.stl
123.6 x 53.7 x 15.8

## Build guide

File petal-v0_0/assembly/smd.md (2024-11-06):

# Petal v0.0 SMD Assembly Notes

Notes from SMD assembly on Friday Oct 25 2024

## Organization

Our system was effective.
Organized by designator, used Altium Assembly assistant tool to guide us.
One person placing, one person preparing.

### Prepare Station

had a pile of component bags.
1. Check next component on assitant, confirm component value and part number.
2. Open the bag, losen tape, place on top of bag.
3. Have one tape ready, one tap on deck, one tape on PnP machine
4. Move bags from left to right based on where they are in the process.
5. Collect completed bags and put off to side.

### Place

1. place components. communicate designators with prepare person.

## Solder paste

- Stencil was too big, had too much paste on PSU
  - Make paste layer smaller, fix issue with paste/mask layer swap
- Designators were confusing, redo them next revision
- Multiple parts for same component, review needs to standardize component types, manufacturers, part numbers, etc.
- Remove 0603s where appropriate.
- Use smaller footprints if able so parts dont shift and "swim" so much.

## Issues

- ESP32 unable to see quality of pad solder. One board doesn't have a funtional blue LED. not sure the cause.
- USB not recognized when C5,6 and R6 are on the lines. they are not necessary. DO NOT PLACE!!!
- GPIO39 is super buggy for IRQ and not reliable. Scratch off mask between LoRa_IRQ pad and adjacent GPIO38 pad before applying solder paste so they bridge. IRQ pin in software has been moved to GPIO38.

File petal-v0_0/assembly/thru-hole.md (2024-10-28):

# Petal v0.0 Thru Hole Assembly Notes

- Don't place fine-pitch headers unless necessary or fix footprint to allow solder mask/prevent bridging. Definitely get rid of exposed gnd plane to prevent shorts.

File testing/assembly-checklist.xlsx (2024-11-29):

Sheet: Check List
Hadware Testing scheme
Task | Completed
Pre- Assembly | FALSE
Visually compare Gerber to manufactured to ensure correct footprints and orientation of components | FALSE
Power continuity test - 3.3V to GND and Vsupply to 3.3V | FALSE
Verify continuity on communications traces | FALSE
Assembly
Place SMT componets | FALSE
Verify orientation | FALSE
Solder all SMT components (hot plate?) | FALSE
Solder all THT components | FALSE
Visual Inspection - check for bridges, Undersoldered joints, cold joints, etc. | FALSE
Re-do continuity testing from pre-assembly | FALSE
Power Supplies
TPSM84203EAB (Hog)
No load current (Quiescent) | FALSE
Inout Voltage Range (4.5V-28V) | FALSE
Vout | FALSE
%Ripple | FALSE
Load testing (0-1A) | FALSE
Vout | FALSE
%Ripple | FALSE
load transient | FALSE
TPS662933P (Ours)
No load current (Quiescent) | FALSE
Input Voltage Range table (3.8V-30V):
Vout | FALSE
%Ripple | FALSE
Load testing table (0A-3A):
Vout | FALSE
%Ripple | FALSE
Test LVD Circuit | FALSE
Load transient | FALSE
ESP-32
Flash via UART | FALSE
Flash via USB | FALSE
write program to cycle LED colour with user button presses | FALSE
flash current version of firmware to confirm wifi functionaliy | FALSE
Card Reader | FALSE
sdWrite | FALSE
wave
lora-pingpong | FALSE

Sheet: TPSM84203EAB (Hog)
Input Voltage [V] | Output Voltage [V] | Ripple [V] | Percent Ripple [%]
4.5 |  |  | #DIV/0!
5 |  |  | #DIV/0!
6 |  |  | #DIV/0!
7 |  |  | #DIV/0!
8 |  |  | #DIV/0!
9 |  |  | #DIV/0!
10 |  |  | #DIV/0!
11 |  |  | #DIV/0!
12 |  |  | #DIV/0!
13 |  |  | #DIV/0!
14 |  |  | #DIV/0!
15 |  |  | #DIV/0!
16 |  |  | #DIV/0!
17 |  |  | #DIV/0!
18 |  |  | #DIV/0!
19 |  |  | #DIV/0!
20 |  |  | #DIV/0!
21 |  |  | #DIV/0!
22 |  |  | #DIV/0!
23 |  |  | #DIV/0!
24 |  |  | #DIV/0!
25 |  |  | #DIV/0!
26 |  |  | #DIV/0!
27 |  |  | #DIV/0!
28 |  |  | #DIV/0!
Load Current [A] | Output Voltage [V] | Ripple [V] | Percent Ripple [%]
0.05 |  |  | #DIV/0!
0.1 |  |  | #DIV/0!
0.15 |  |  | #DIV/0!
0.2 |  |  | #DIV/0!
0.25 |  |  | #DIV/0!
0.3 |  |  | #DIV/0!
0.35 |  |  | #DIV/0!
0.4 |  |  | #DIV/0!
0.45 |  |  | #DIV/0!
0.5 |  |  | #DIV/0!
0.55 |  |  | #DIV/0!
0.6 |  |  | #DIV/0!
0.65 |  |  | #DIV/0!
0.7 |  |  | #DIV/0!
0.75 |  |  | #DIV/0!
0.8 |  |  | #DIV/0!
0.85 |  |  | #DIV/0!
0.9 |  |  | #DIV/0!
0.95 |  |  | #DIV/0!
1 |  |  | #DIV/0!
1.05 |  |  | #DIV/0!
1.1 |  |  | #DIV/0!
1.15 |  |  | #DIV/0!
1.2 |  |  | #DIV/0!
1.25 |  |  | #DIV/0!
1.3 |  |  | #DIV/0!
1.35 |  |  | #DIV/0!
1.4 |  |  | #DIV/0!
1.45 |  |  | #DIV/0!
1.5 |  |  | #DIV/0!
Load Transient: 0.375A - 1.125A @ 1A/uS | Result
% Overshoot
Settle time

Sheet: TPS62933P (Ours)
Input Voltage [V] | Output Voltage [V] | Ripple [V] | Percent Ripple [%]
3.8 |  |  | #DIV/0!
4.5 |  |  | #DIV/0!
5 |  |  | #DIV/0!
6 |  |  | #DIV/0!
7 |  |  | #DIV/0!
8 |  |  | #DIV/0!
9 |  |  | #DIV/0!
10 |  |  | #DIV/0!
11 |  |  | #DIV/0!
12 |  |  | #DIV/0!
13 |  |  | #DIV/0!
14 |  |  | #DIV/0!
15 |  |  | #DIV/0!
16 |  |  | #DIV/0!
17 |  |  | #DIV/0!
18 |  |  | #DIV/0!
19 |  |  | #DIV/0!
20 |  |  | #DIV/0!
21 |  |  | #DIV/0!
22 |  |  | #DIV/0!
23 |  |  | #DIV/0!
24 |  |  | #DIV/0!
25 |  |  | #DIV/0!
26 |  |  | #DIV/0!
27 |  |  | #DIV/0!
28 |  |  | #DIV/0!
29 |  |  | #DIV/0!
30 |  |  | #DIV/0!
Load Current [A] | Output Voltage [V] | Ripple [V] | Percent Ripple [%]
0.05 |  |  | #DIV/0!
0.1 |  |  | #DIV/0!
0.15 |  |  | #DIV/0!
0.2 |  |  | #DIV/0!
0.25 |  |  | #DIV/0!
0.3 |  |  | #DIV/0!
0.35 |  |  | #DIV/0!
0.4 |  |  | #DIV/0!
0.45 |  |  | #DIV/0!
0.5 |  |  | #DIV/0!
0.55 |  |  | #DIV/0!
0.6 |  |  | #DIV/0!
0.65 |  |  | #DIV/0!
0.7 |  |  | #DIV/0!
0.75 |  |  | #DIV/0!
0.8 |  |  | #DIV/0!
0.85 |  |  | #DIV/0!
0.9 |  |  | #DIV/0!
0.95 |  |  | #DIV/0!
1 |  |  | #DIV/0!
1.2 |  |  | #DIV/0!
1.4 |  |  | #DIV/0!
1.6 |  |  | #DIV/0!
1.8 |  |  | #DIV/0!
2 |  |  | #DIV/0!
2.25 |  |  | #DIV/0!
2.5 |  |  | #DIV/0!
Load Transient: 0.5A - 2.5A @ 0.8A/uS | Result
% Overshoot
Settle time
Column1 | LifeP04 *2 | Operational | pB/AGM | Operational2 | 12V lithium | Operational3
Disconnect Voltage | 6 | FALSE | 11.51 | FALSE | 12 | FALSE
Reconnect Voltage | 6.6 | FALSE | 12.06 | FALSE | 13 | FALSE

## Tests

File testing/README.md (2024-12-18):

# testing

Testing code and procedures for Petal hardware.
Testing results for each Petal version will be found in that version's folder.

## File Tree Overview

Navigating this directory

### lora-pingpong

Code to test the functionality of the LoRa module on the Petal.
Requires PlatformIO.

### lora-sleep

Code to test the LoRa wakeup from light sleep.
Requires platformIO.

### LoraSwr

Code to test hardware SWR and radio performance.
Requires PlatformIO and the test setup found in the test plan.

### sdWrite

Code to test the functionality of the SD card on the Petal.
Requires PlatformIO.

### sleep-test

Code to test light sleep and wakeup sources.
Requires PlatformIO.

### assembly-checklist.xlsx

Pre- and post-assembly checklist. Ensures the board has been built correctly before official testing can begin.

### floar-test-plan.docx

Official test plan. Requires that the Petal has AVAlink firmware from _flora-software_. 
All tests must pass for requirements to be met.
Use the supporting checklists for determining pass-fail criteria.

### lvd-testing.xlsx & psu-testing.xlsx

Supporting checklists for use with the official test plan.

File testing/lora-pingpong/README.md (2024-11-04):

# lora-pingpong GUIDE

How to use this code to test a LoRa module.

1. Open the "lora-pingpong.code-workspace" file in VS Code.
2. Connect a working LoRa board. Supported boards are Petal Radio v0.0, LilyGo T3 S3 v1.2 SX1262, and the Heltec 32 LoRa V3.
3. Uncomment the board you would like to use in main.cpp.
4. Select the correct PIO environment.
5. Upload.
6. Open the Serial port.
7. Connect the Petal under test ("DUT").
8. Comment out the previous board define and uncomment the Petal define.
9. Uncomment the "INITIATING_NODE" define
10. Upload
11. Open the serial monitor on both and observe the packets ping ponging. If not, troubleshoot.

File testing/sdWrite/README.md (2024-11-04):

# sdWrite GUIDE

How to use this code to test the Petal SD card

1. Open the "sdWrite.code-workspace" file in VS Code.
2. Upload "history.csv" to a micro SD card.
3. Insert the SD card into the Petal.
4. Upload the code. 
5. Open the serial monitor. The contents of history.csv should be printed out into the monitor.

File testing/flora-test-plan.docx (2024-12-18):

Petal Radio Test Plan

Flora communications | Camosun College

21 october 2024

A. huinink, c. gillingham, t. osler

V1.0

# Accessibility

Testing the accessibility of the FloraNet service for users. Covers all of 1-SW.

## Mobile Devices

Test the accessibility of the user interface on a mobile device.

1. Provide power to a Petal Radio using the micro-USB or an appropriate battery configuration.
2. Have a friend/parent follow these instructions without assistance:
a) Press the User button to activate the node.
b) Using a smartphone, connect to the FloraNet Wi-Fi network.
c) Scan the QR code or navigate to floranet.local in a web browser (CHECKPOINT).

### Pass/Fail

Criteria for user accessibility requirements. The order of the below criteria corresponds to the order that checkpoints appear in the testing steps.

1-SW-C1.0. The user interface is rendered correctly and readably on a mobile device.

## PCs

Test the accessibility of the user interface on a PC/desktop computer.

3. Provide power to a Petal Radio using the micro-USB or an appropriate battery configuration.
4. Have a friend/parent follow these instructions without assistance:
  a. Press the User button to active the node.
  b. Using a desktop or laptop computer, connect to the FloraNet Wi-Fi network.
  c. Navigate to floranet.local in a web browser (CHECKPOINT).

### Pass/Fail

Criteria for user accessibility requirements. The order of the criteria below corresponds to the order that checkpoints appear in the testing steps.

1-SW-C1.1. The user interface is rendered correctly and readably on a desktop/laptop computer.

# LoRa Networking

Tests the LoRa networking capabilities. Covers all of 2-SW, 3-SW, 5-SW, 10-HW.

## LoRa Tx/Rx & Collision Avoidance

Purposefully introduce the potential for packet collisions to test the performance of the collision avoidance protocol wde designed for the FloraNet network.

1. Connect a smartphone or PC to each node (Mobile Devices).
2. Send a message in the web application from both nodes with at least a 30 second delay between pressing send on the applications (2 CHECKPOINTS).
3. Next, introduce a packet collision scenario. Enter a message into the text box of both nodes’ web applications, but do not press send yet.
4. Once both applications are loaded with a message, press the send button on both node applications at the same time.
5. See that both messages are displayed correctly in the application at both nodes. If one or both messages do not appear, those packets were lost in a collision. Record the success or failure for that packet collision scenario.
6. Repeat Steps 3, 4, and 5 nine more times, for a total of 10 potential packet collision scenarios. (CHECKPOINT).

### Pass/Fail

The order of the below criteria corresponds to the order that checkpoints appear in the testing steps.

2-SW-C1. The sent messages appear in the other device’s web application.

3-SW-C1. The messages appear in the chat box in the order they were sent with formatting and information that indicates which node sent each message (i.e. transmitted messages appear on the right in green and received messages appear on the left in blue with the associated node ID).

5-SW-C1. Out of 10 packet collision scenarios, 3 or fewer messages are lost (packet loss < 20%).

## Impedance Match

Test the match between the LoRa module and the antenna.

1. Connect the IPEX connector on the LoRa module to a VSWR tap DUT input.
2. Connect a LoRa antenna to the VSWR tap DUT output.
3. Connect a spectrum analyser to the VSWR tap output.
4. Set the spectrum analyser to view the ISM band (900-928MHz) with persistence enabled.
5. Put the node into USB mode following the user manual instructions.
6. Provide 5V power to the node.
7. Put the node into its test configuration* following the user manual instructions.
8. Clear the persistent traces on the spectrum analyser.
9. Press the User button on the node to initiate the test.
10. Upon completion of the test, save the spectrum analyser trace.
11. Note the frequency and peak power of the smallest peak on the analyser output (CHECKPOINT).

*The test configuration transmits LoRa packets at 14dBm at frequency slots across the ISM band.

### Pass/Fail

The order of the below criteria corresponds to the order that checkpoints appear in the testing steps.

10-HW-C1. The smallest peak in the ISM band has a peak power less than 4dBm (VSWR < 2).

# Power

Tests the power and battery management capabilities of the repeater node. Covers 4-HW, 8-HW, 9-HW, 11-HW, 12-SW.

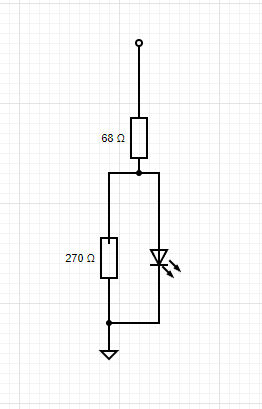
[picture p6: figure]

## Low Voltage Disconnect

3V3 - Left J9 pin

Figure 1: LVD testing load circuit.

Test the low voltage disconnect capability of the node that protects batteries from full discharge.

1. Use a variable voltage supply that can provide at least 0V-20V and 3A and set the supply to 7V.
2. Follow the instructions in the user manual to set the power supply to the TPS62933P option in 6V Lithium mode.
3. Remove the jumper from J9 to expose the pins.
4. Connect the circuit shown in Figure 1 from the left-most pin of J9 to ground.
5. Connect the power supply to the board at the battery terminal block and power up the board.
6. Measure the input voltage across the battery terminal screw heads and verify it is 7.00V.
7. Measure the output voltage across the load circuit and confirm it is between 3.25V and 3.35V.
8. Place a lead on that pin and continue to monitor the voltage there using an oscilloscope.
9. Set the oscilloscope to single capture, triggering on a falling edge between 3.3V and 0V and capturing at least 20ms after the falling edge.
10. Slowly decrease the input voltage at a rate of ≈10mV/second until the load circuit LED turns off. This is the low voltage disconnect.
11. Record the input voltage that caused the low voltage disconnect in Table 1 in the appropriate column.
12. Save the oscilloscope trace. If the trace shows the load resistor voltage cycling between 0V and 3.3V after the initial power disconnect, put a “y” in the Power Cycling row of Table 1, otherwise put an “n”.
13. Repeat Steps 5-12 for the 12V Pb/AGM battery mode and the 12V Lithium mode but have the starting voltages about 0.5V higher than the “Reconnect” target voltages in Table 1 (CHECKPOINT).

### Pass/Fail

Complete Table 1 below and compare to the requirement specifications.

Table 1: Low voltage disconnect testing values.

4-HW-C1.1. All actions in Table 1 pass.

## Power Supply

Tests the TPS62933P switching power supply circuit we designed for the Petal v0.0.

1. Put Petal v0.0 into USB mode by following the user manual instructions.
2. Remove the jumper from J9 to expose the pins.
3. Connect a programmable load to the far left pin of J9 and to ground.
4. Set the load to draw 10mA at 3.3V.
5. Connect a power supply (see “Supply Voltage” for the applicable mode voltage in Table 2).
6. Measure the output voltage across the programmable load and note it in Table 2.
7. Connect an oscilloscope across the programmable load.
8. Measure the ripple voltage across the programmable load with the oscilloscope, record it in Table 2, and save the trace data for later documentation.
9. Increase the load current draw to 650mA.
10. Repeat Steps 6-8.
11. Program the load to quickly increase from 10mA to 650mA, hold for 5ms, and then decrease back down to 10mA.
12. Set the oscilloscope to perform a single capture on an AC-coupled rising edge with a vertical range of -350mV to 350mV and a horizontal range of 10ms.
13. Run the load transient.
14. Using the oscilloscope, measure the peak-to-peak voltage change for the two load transient peaks. Divide this number in half to average the two peaks and record in Table 2.
15. At each transient spike, estimate the time it took for the voltage to correct back to it’s typical 3.3V waveform. Record in Table 2.
16. Repeat Steps 4-15 for the remaining modes in Table 2 (CHECKPOINT).

### Pass/Fail

Complete Table 2 below and compare to the requirement specifications.

Table 2: Power supply unit testing criteria.

8-HW-C1.0 & C1.1. All modes have a “PASS” grade.

## Efficiency

Tests that the firmware switches between power modes based on demands.

1. Put the Petal v0.0 into 6V Li mode following instructions from the user manual.
2. Connect a 7V power supply to the board through an ammeter.
3. Ensure that the Wi-Fi access point is not on.
4. Record the current drawn in this standby mode.
5. Press the User Switch to initiate the Wi-Fi access point.
6. Ensure the Wi-Fi access point is up (CHECKPOINT).
7. Record the current drawn in this state.
8. Wait 5 minutes.
9. Ensure the access point has turned off (CHECKPOINT).
10. Measure the current drawn by the board again (CHECKPOINT).

### Pass/Fail

Criteria for efficiency requirements. The order of the below criteria corresponds to the order that checkpoints appear in the testing steps.

11-HW-C1. The access point is available.

11-HW-C2. The access point turns off after 5 minutes of inactivity.

12-HW-C1. The current draw when the Wi-Fi access point is up is greater than the current draw when the node is in a standby mode.

# Appendix – Requirements and Tests v1.1

A legend is available in Table 4 describing the reference number syntaxes for each section.

Table 3: Requirement Specifications, related tests, and pass/fail criteria for the prototyping stage of Petal radio and FloraNet.

Reference Number | Requirement | Test | Criteria | Pass/Fail
1-SW | R.1 – The user interface MUST be accessible through a modern web browser without the need for a separate application. | T1.0 – Connect a smartphone with a modern browser to the node and navigate to floranet.local. | C1.0 – UI is rendered and readable on a mobile device. | PASS
| | T1.1 – Connect a PC to the node and navigate to floranet.local. | C1.1 – UI is rendered and readable on a PC. | PASS
2-SW | R1 – Users MUST be able to send LoRa packets using the web interface from one device to another. | T1 – Send a message using the UI to another node | C1 – The sent message is shown on the other device's UI | PASS
3-SW | R1 – Chats on UI must have a username or device identifier and appear in the order the messages were received. | T1 – Send chat messages from multiple devices over the UI | C1 – The UI renders chat history with usernames in chronological order according to the time the message was received. | PASS
4-HW | R1 – The repeater node MUST monitor battery voltage and disconnect when dropping below the low voltage threshold. | T1 – Supply voltage to the node with a variable power supply and document which voltages result in disconnect and reconnect. The node voltage monitor will be compared to that of the power supply and measured with an external meter. | C1.0 – The reported battery voltage is accurate within 3%. | PASS
| R2 – The repeater node low-voltage disconnect MUST implement hysteresis to prevent power cycling. | | C1.1 – The load disconnects when the battery voltage drops below the low voltage threshold and turns back on when the battery charges above threshold voltage. The implemented hysteresis prevents power cycling of the device. | PASS
| F1 – The repeater SHOULD indicate to the rest of the mesh network that it is powering down. | | FC1 – Before the low-voltage disconnect, the device transmits an alert that it is powering down.
5-SW | R1 – The software MUST implement a collision avoidance or multiple access protocol that deals with the hidden-node problem | T1 – Transmit a LoRa packet from two devices to a single receiver at the same time without a connection between the two senders to coordinate between them | C1.0 – Packet loss of less than 15%. | PASS
| | | C1.1 – Messages are displayed in the UI in the correct order. | PASS
6-HW | R1 – MUST Design and order a PCB | T1 – Before each revision is submitted for manufacturing, it will be subject to an internal review by the group and an external review by the Capstone Committee. | C1 – The PCB design passes an internal review process and review from the Capstone Committee. | PASS
7-HW | R1 – MUST have a bespoke enclosure. F1 – SHOULD be protected against rain and moisture ingress | T1 – The enclosure will be inspected by professors. T2 – Third-party parts like cable glands are IPX4 certified. | C1 – All third-party enclosure components have IPX4 or greater certification. | PASS
8-HW | R1 – Voltage regulator MUST effectively provide the required 3.3V to the hardware for a range of typical battery voltages. | T1 – Input a range of voltages from 3.8V-20V and measure the voltage regulator output. | C1.0 – The hardware receives a stable 3.3V +/- 0.1V out across the range of test voltages. | PASS
| | | C1.1 – The output voltage, ripple voltage, and load transient response meets the hardware specifications provided by the manufacture in the datasheet. | PASS
9-HW | R1 – MUST provide recommendations for sizing batteries and solar panels based on expected insolation. | T1 – Use recommendations to size solar and battery power for a mock installation at Camosun College using insolation data for that location. | C1 - Recommended panel wattages and battery Ah meet or exceed node requirements as calculated by our power audit (datasheet specifications, duty cycle, solar insolation modeling) | PASS
10-HW | R1 – Antennas MUST be well matched to the driving Hardware | T1 – SWR/Impedance testing of antenna and source using VNA (may require tuning to meet these requirements) | C1 – Source impedance is matched to antenna so that VSWR < 2 and return loss < -10 dB at some point between 900-928MHz. | PASS
11-HW | R1 – Nodes MUST incorporate an accessible user button at access points for users to initiate the web server. | T1 – Check that the Wi-Fi access point is powered down. Press the user button to initiate the Wi-Fi access point. | C1 – The Wi-Fi access point is available after pressing the user button. | PASS
| R2 – The Wi-Fi access point MUST time-out after 5 minutes of inactivity to save power. | T2 – Leave the access point for 5 minutes without activity. | C2 – The Wi-Fi access point is disabled after 5 minutes of inactivity. | PASS
12- SW | R1 – The firmware has multiple power consumption modes to conserve battery. | T1 – Measure node current draw when access point is up and when it is down. | C1 – The current draw in AP down mode is less than the current draw in active mode. | PASS
| F1 – An LED indicates different states to the user. offline until the battery can be recharged. | | FC1.0 – The LED indicates a New Message state. | C
| | | FC1.1 – The LED indicates low voltage. | NC

## Legend

Table 4: A legend describing the syntax used for the reference numbers.

Reference Number | Requirement | Testing | Pass/Fail Criteria
#-(ID): HW: Indicates a hardware requirement SW: Indicates a software requirement | R#: A requirement, something the component MUST have, followed by an identification number that begins at 0. F#: A feature, something the component SHOULD have, followed by an identification number that begins at 0. | T#.#: The test identification number. The number matches the requirement it corresponds to. If multiple tests relate to the same requirement, a second reference number is added with a decimal point. FT.#.#: Same as requirement tests but relates to a feature. | C#.#.#: The criteria identification number. The number matches the test it corresponds to. If multiple criteria exist for the same test, a second sub-reference number is added. A Pass is required. FC.#.#.#: Same as requirement criteria but relates to a feature and is not required to pass.

flora-test-plan.docx 2 Version 1.0

ECET 291 – Project Management 21 October 2024 CG, TO, AH

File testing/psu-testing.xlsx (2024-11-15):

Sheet: Sheet1
Mode | Supply voltage (V) | Load Current (mA) | Output Voltage (V) | Ripple Voltage (V) | Load Transient Response | Low-High | High-Low | Average | Pass/Fail
USB | 5V | 10 |  |  | Voltage Change (mV) | 0 | 0 | 0 | FAIL
 |  | 650 |  |  | Correction time (us) | 0 | 0 | 0
6V Li | 6.7V | 10 |  |  | Voltage Change (mV) | 0 | 0 | 0 | FAIL
 |  | 650 |  |  | Correction time (us) | 0 | 0 | 0
12V Pb/AGM | 12.6V | 10 |  |  | Voltage Change (mV) | 0 | 0 | 0 | FAIL
 |  | 650 |  |  | Correction time (us) | 0 | 0 | 0
12V Li | 13.5V | 10 |  |  | Voltage Change (mV) | 0 | 0 | 0 | FAIL
 |  | 650 |  |  | Correction time (us) | 0 | 0 | 0

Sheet: TPSM84203EAB (Hog)
Input Voltage [V] | Output Voltage [V] | Ripple [V] | Percent Ripple [%] | Mode | Supply voltage (V) | Load Current (mA) | Output Voltage (V) | Ripple Voltage (V) | Load Transient Response | Low-High | High-Low | Average | Pass/Fail
4.5 |  |  | #DIV/0! | USB | 5V | 10 |  |  | Voltage Change (mV) | 0 | 0 | 0 | FAIL
5 |  |  | #DIV/0! |  |  | 650 |  |  | Correction time (us) | 0 | 0 | 0
6 |  |  | #DIV/0! | 6V Li | 6.7V | 10 |  |  | Voltage Change (mV) | 0 | 0 | 0 | FAIL
7 |  |  | #DIV/0! |  |  | 650 |  |  | Correction time (us) | 0 | 0 | 0
8 |  |  | #DIV/0! | 12V Pb/AGM | 12.6V | 10 |  |  | Voltage Change (mV) | 0 | 0 | 0 | FAIL
9 |  |  | #DIV/0! |  |  | 650 |  |  | Correction time (us) | 0 | 0 | 0
10 |  |  | #DIV/0! | 12V Li | 13.5V | 10 |  |  | Voltage Change (mV) | 0 | 0 | 0 | FAIL
11 |  |  | #DIV/0! |  |  | 650 |  |  | Correction time (us) | 0 | 0 | 0
12 |  |  | #DIV/0!
13 |  |  | #DIV/0!
14 |  |  | #DIV/0!
15 |  |  | #DIV/0!
16 |  |  | #DIV/0!
17 |  |  | #DIV/0!
18 |  |  | #DIV/0!
19 |  |  | #DIV/0!
20 |  |  | #DIV/0!
21 |  |  | #DIV/0!
22 |  |  | #DIV/0!
23 |  |  | #DIV/0!
24 |  |  | #DIV/0!
25 |  |  | #DIV/0!
26 |  |  | #DIV/0!
27 |  |  | #DIV/0!
28 |  |  | #DIV/0!
Load Current [A] | Output Voltage [V] | Ripple [V] | Percent Ripple [%]
0.05 |  |  | #DIV/0!
0.1 |  |  | #DIV/0!
0.15 |  |  | #DIV/0!
0.2 |  |  | #DIV/0!
0.25 |  |  | #DIV/0!
0.3 |  |  | #DIV/0!
0.35 |  |  | #DIV/0!
0.4 |  |  | #DIV/0!
0.45 |  |  | #DIV/0!
0.5 |  |  | #DIV/0!
0.55 |  |  | #DIV/0!
0.6 |  |  | #DIV/0!
0.65 |  |  | #DIV/0!
0.7 |  |  | #DIV/0!
0.75 |  |  | #DIV/0!
0.8 |  |  | #DIV/0!
0.85 |  |  | #DIV/0!
0.9 |  |  | #DIV/0!
0.95 |  |  | #DIV/0!
1 |  |  | #DIV/0!
1.05 |  |  | #DIV/0!
1.1 |  |  | #DIV/0!
1.15 |  |  | #DIV/0!
1.2 |  |  | #DIV/0!
1.25 |  |  | #DIV/0!
1.3 |  |  | #DIV/0!
1.35 |  |  | #DIV/0!
1.4 |  |  | #DIV/0!
1.45 |  |  | #DIV/0!
1.5 |  |  | #DIV/0!
Load Transient: 0.375A - 1.125A @ 1A/uS | Result
% Overshoot
Settle time

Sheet: TPS62933P (Ours)
Line Regulation
Input Voltage [V] | Output Voltage [V] | Ripple [V] | Percent Ripple [%]
3.8 |  |  | #DIV/0!
4.5 |  |  | #DIV/0!
5 |  |  | #DIV/0!
6 |  |  | #DIV/0!
7 |  |  | #DIV/0!
8 |  |  | #DIV/0!
9 |  |  | #DIV/0!
10 |  |  | #DIV/0! |  | Ripple and transient
11 |  |  | #DIV/0!
12 |  |  | #DIV/0! |  | EMI
13 |  |  | #DIV/0! |  | Mode | Supply voltage (V) | Load Current (mA) | Output Voltage (V) | Ripple Voltage (V) | Load Transient Response | Low-High | High-Low | Average | Pass/Fail
14 |  |  | #DIV/0! |  | USB | 5V | 10 |  |  | Voltage Change (mV) | 0 | 0 | 0 | FAIL
15 |  |  | #DIV/0! |  |  |  | 650 |  |  | Correction time (us) | 0 | 0 | 0
16 |  |  | #DIV/0! |  | 6V Li | 6.7V | 10 |  |  | Voltage Change (mV) | 0 | 0 | 0 | FAIL
17 |  |  | #DIV/0! |  |  |  | 650 |  |  | Correction time (us) | 0 | 0 | 0
18 |  |  | #DIV/0! |  | 12V Pb/AGM | 12.6V | 10 |  |  | Voltage Change (mV) | 0 | 0 | 0 | FAIL
19 |  |  | #DIV/0! |  |  |  | 650 |  |  | Correction time (us) | 0 | 0 | 0
20 |  |  | #DIV/0! |  | 12V Li | 13.5V | 10 |  |  | Voltage Change (mV) | 0 | 0 | 0 | FAIL
21 |  |  | #DIV/0! |  |  |  | 650 |  |  | Correction time (us) | 0 | 0 | 0
22 |  |  | #DIV/0!
23 |  |  | #DIV/0! |  | REFERENCE CAPTURES
24 |  |  | #DIV/0!
25 |  |  | #DIV/0!
26 |  |  | #DIV/0!
27 |  |  | #DIV/0! |  | NO EMI
28 |  |  | #DIV/0! |  | Mode | Supply voltage (V) | Load Current (mA) | Output Voltage (V) | Ripple Voltage (V) | Load Transient Response | Low-High | High-Low | Average | Pass/Fail
29 |  |  | #DIV/0! |  | USB | 5V | 10 |  |  | Voltage Change (mV) | 0 | 0 | 0 | FAIL
30 |  |  | #DIV/0! |  |  |  | 650 |  |  | Correction time (us) | 0 | 0 | 0
 |  |  |  |  | 6V Li | 6.7V | 10 |  |  | Voltage Change (mV) | 0 | 0 | 0 | FAIL
Load Regulation |  |  |  |  |  |  | 650 |  |  | Correction time (us) | 0 | 0 | 0
Load Current [A] | Output Voltage [V] | Ripple [V] | Percent Ripple [%] |  | 12V Pb/AGM | 12.6V | 10 |  |  | Voltage Change (mV) | 0 | 0 | 0 | FAIL
0.05 |  |  | #DIV/0! |  |  |  | 650 |  |  | Correction time (us) | 0 | 0 | 0
0.1 |  |  | #DIV/0! |  | 12V Li | 13.5V | 10 |  |  | Voltage Change (mV) | 0 | 0 | 0 | FAIL
0.15 |  |  | #DIV/0! |  |  |  | 650 |  |  | Correction time (us) | 0 | 0 | 0
0.2 |  |  | #DIV/0!
0.25 |  |  | #DIV/0! |  | REFERENCE CAPTURES
0.3 |  |  | #DIV/0!
0.35 |  |  | #DIV/0!
0.4 |  |  | #DIV/0!
0.45 |  |  | #DIV/0!
0.5 |  |  | #DIV/0!
0.55 |  |  | #DIV/0!
0.6 |  |  | #DIV/0!
0.65 |  |  | #DIV/0!
0.7 |  |  | #DIV/0!
0.75 |  |  | #DIV/0!
0.8 |  |  | #DIV/0!
0.85 |  |  | #DIV/0!
0.9 |  |  | #DIV/0!
0.95 |  |  | #DIV/0!
1 |  |  | #DIV/0!
1.2 |  |  | #DIV/0!
1.4 |  |  | #DIV/0!
1.6 |  |  | #DIV/0!
1.8 |  |  | #DIV/0!
2 |  |  | #DIV/0!
2.25 |  |  | #DIV/0!
2.5 |  |  | #DIV/0!
Load Transient: 0.5A - 2.5A @ 0.8A/uS | Result
% Overshoot
Settle time
Column1 | LifeP04 *2 | Operational | pB/AGM | Operational2 | 12V lithium | Operational3
Disconnect Voltage | 6 | FALSE | 11.51 | FALSE | 12 | FALSE
Reconnect Voltage | 6.6 | FALSE | 12.06 | FALSE | 13 | FALSE

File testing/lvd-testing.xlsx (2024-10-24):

6V Li
Targets | Disconnect | 6
 | Reconnect | 6.6
Action | Voltage (V) | Pass/Fail
Disconnect |  | FAIL
Reconnect |  | FAIL
Power Cycling | y | FAIL
12V Pb/AGM
Targets | Disconnect | 11.51
 | Reconnect | 12.06
Action | Voltage (V) | Pass/Fail
Disconnect |  | FAIL
Reconnect |  | FAIL
Power Cycling | y | FAIL
12V Li
Targets | Disconnect | 12
 | Reconnect | 13
Action | Voltage (V) | Pass/Fail
Disconnect |  | FAIL
Reconnect |  | FAIL
Power Cycling | y | FAIL

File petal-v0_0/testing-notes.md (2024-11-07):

# testing notes

05 Nov 2024
- IRQ on 39 is super buggy. Jumpering to 38 makes it work totally fine. Recommend moving IRQ to 38 in firmware. During build, scratch off mask between pads for gpio38 and adjacent Lora_IRQ so they bridge.

07 Nov 2024
- GPIO38 and 39 are not RTC IOs on the S3 (These are GPIO 0-21), so it cannot be used to wake up from deep sleep (only light sleep using esp_sleep_enable_gpio_wakeup()). Future revisions that want to use deep sleep will need to put Lora IRQ on an RTCIO pin.

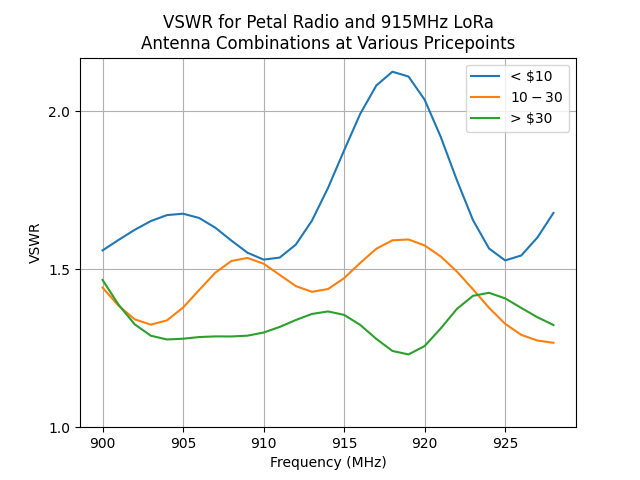
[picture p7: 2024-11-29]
petal-v0_0/test-results/radio-testing/vswr.png

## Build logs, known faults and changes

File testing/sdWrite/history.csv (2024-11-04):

paylod | nodeID | SOS
Hello world | 5 | 0
its me | 0 | 0
How have you been | 3 | 0
node 4 cheking in | 4 | 0
SOS | 3 | 1
on our way | 2 | 0

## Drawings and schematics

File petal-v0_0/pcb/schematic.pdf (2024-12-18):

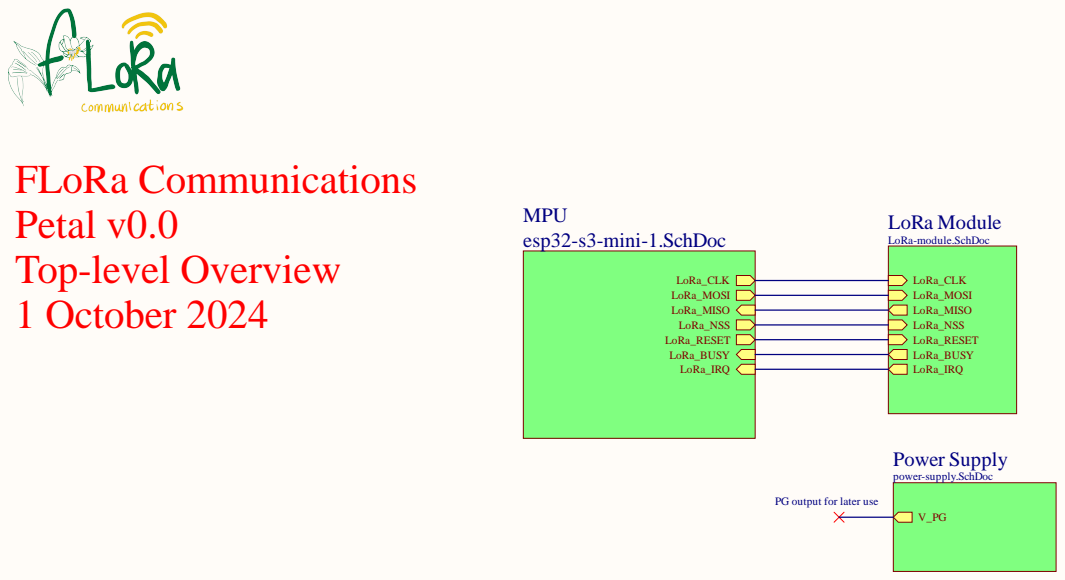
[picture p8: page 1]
<SCH DWG NO>; SIZE; DWG NO.; FILE NAME; SHEET; CAGE CODE; ASSY DWG:; FAB DWG:; PCB DWG:; <PCB DWG NO>; PROJECT REVISION:; DOCUMENT REVISION:; DESIGN ITEM:; Version; control disabled Version control disabled

DWG NO: <ASSY DWG NO> | REV:

THIS DOCUMENT AND THE DATA DISCLOSED HEREIN OR HEREWITH IS THE PROPERTY OF ALTIUM LIMITED AND MAY BE FREELY DISTRIBUTED IN WHOLE. NO RIGHTS ARE RESERVED OR EXPRESS OR IMPLIED WARANTEE GIVEN. | MPU LoRa Module LoRa-module.SchDoc esp32-s3-mini-1.SchDoc | REVISION | DESCRIPTION | DATE | APPROVED

FLoRa Communications
Petal v0.0
Top-level Overview
1 October 2024

Power Supply power-supply.SchDoc

PG output for later use

DWG NO: REV:

DATE | PROJECT * | * * APPROVALS * *

ENG: * | --/--/--

DSN: * | --/--/--

CHK: * | --/--/--

REFERENCE DOCUMENTS
<BOM DOC NO>

<ASSY DWG NO>
<FAB DWG NO>

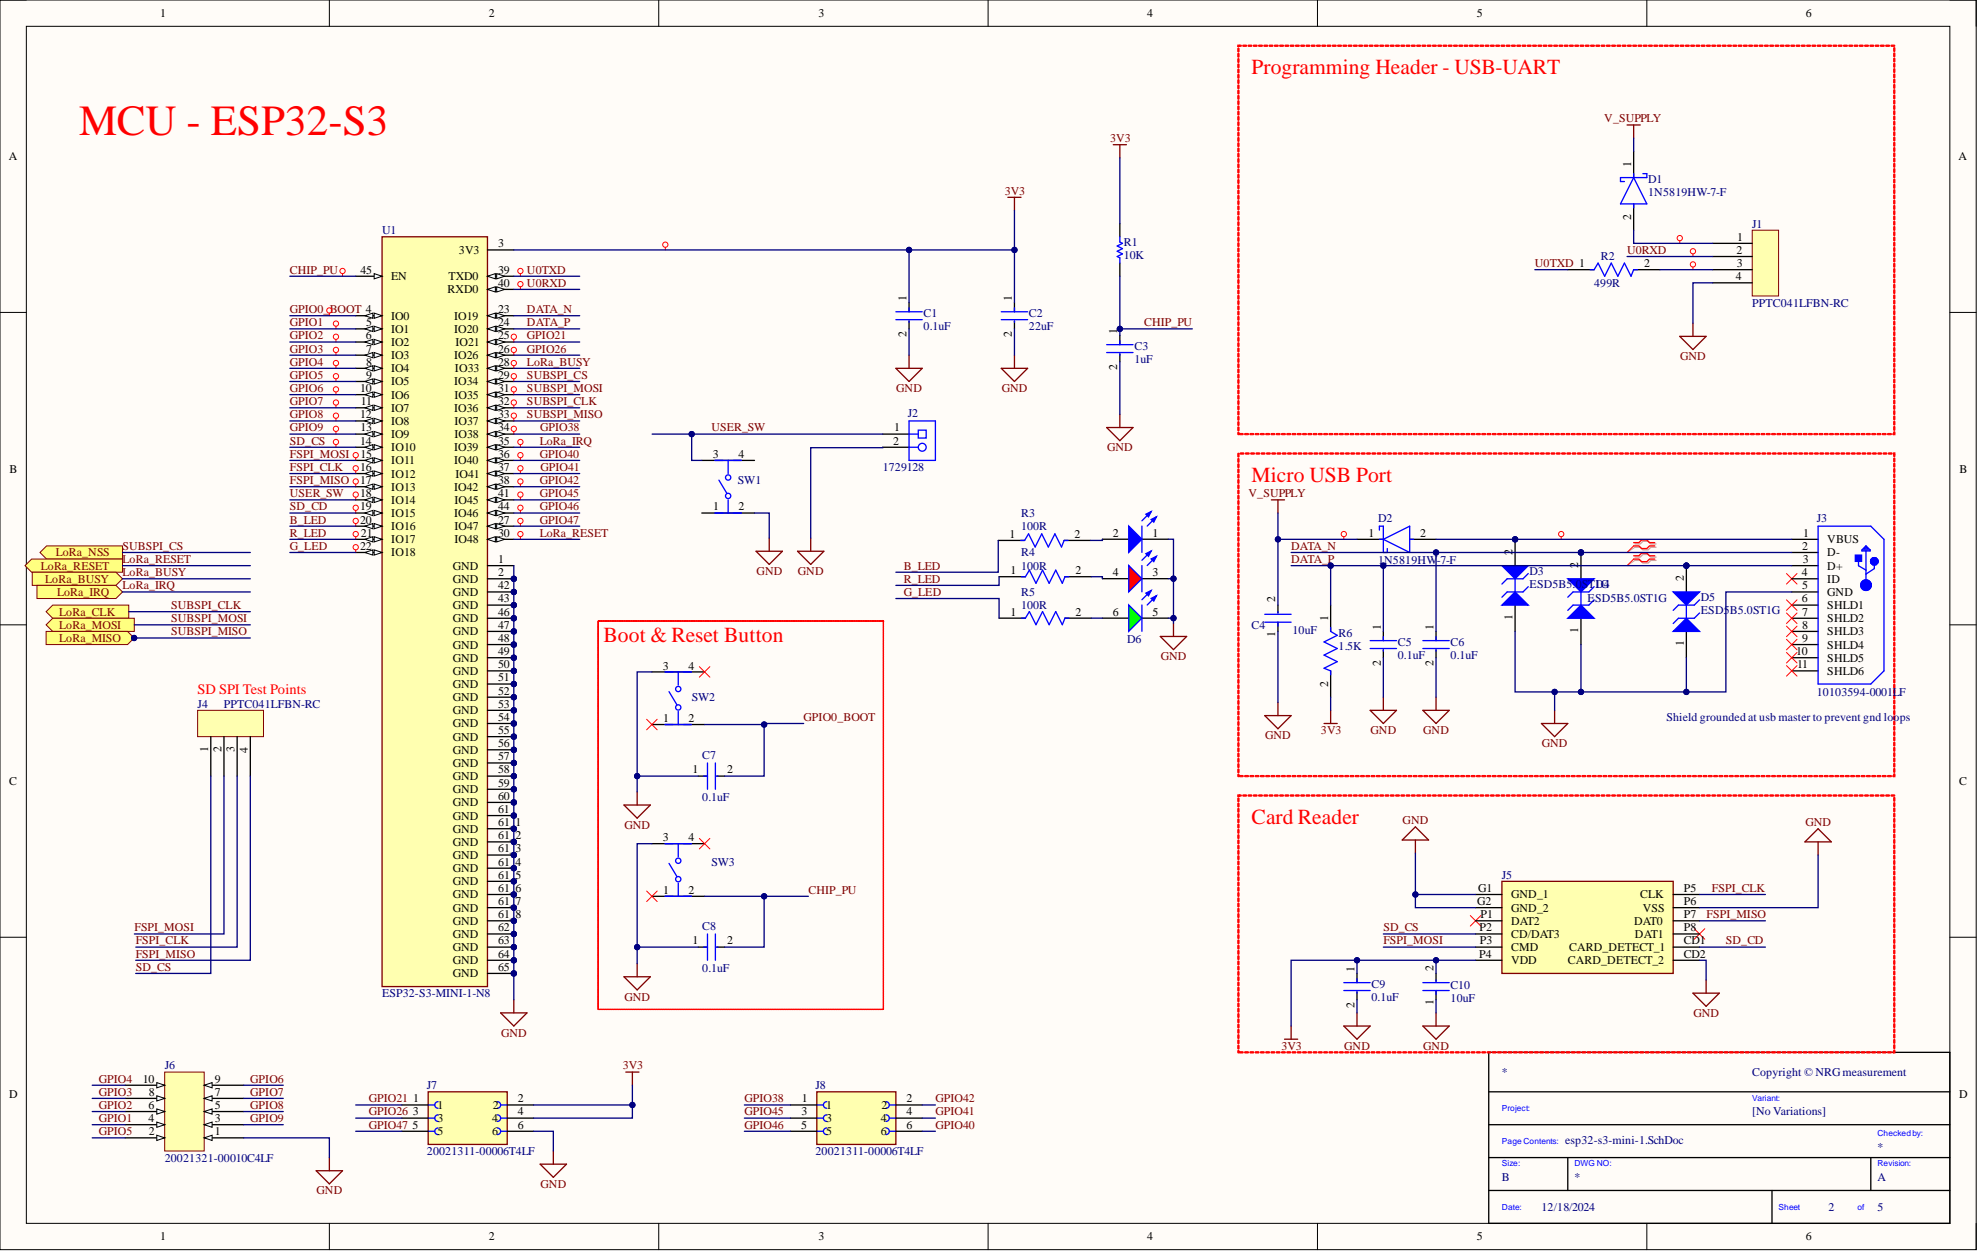
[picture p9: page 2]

Programming Header - USB-UART

D5 ESD5B5.0ST1G | SHLD1 6

SD SPI Test Points

Shield grounded at usb master to prevent gnd loops

Page Contents: esp32-s3-mini-1.SchDoc

Size: B | DWG NO: * | Revision: A

Date: 12/18/2024 | Sheet 2 of 5

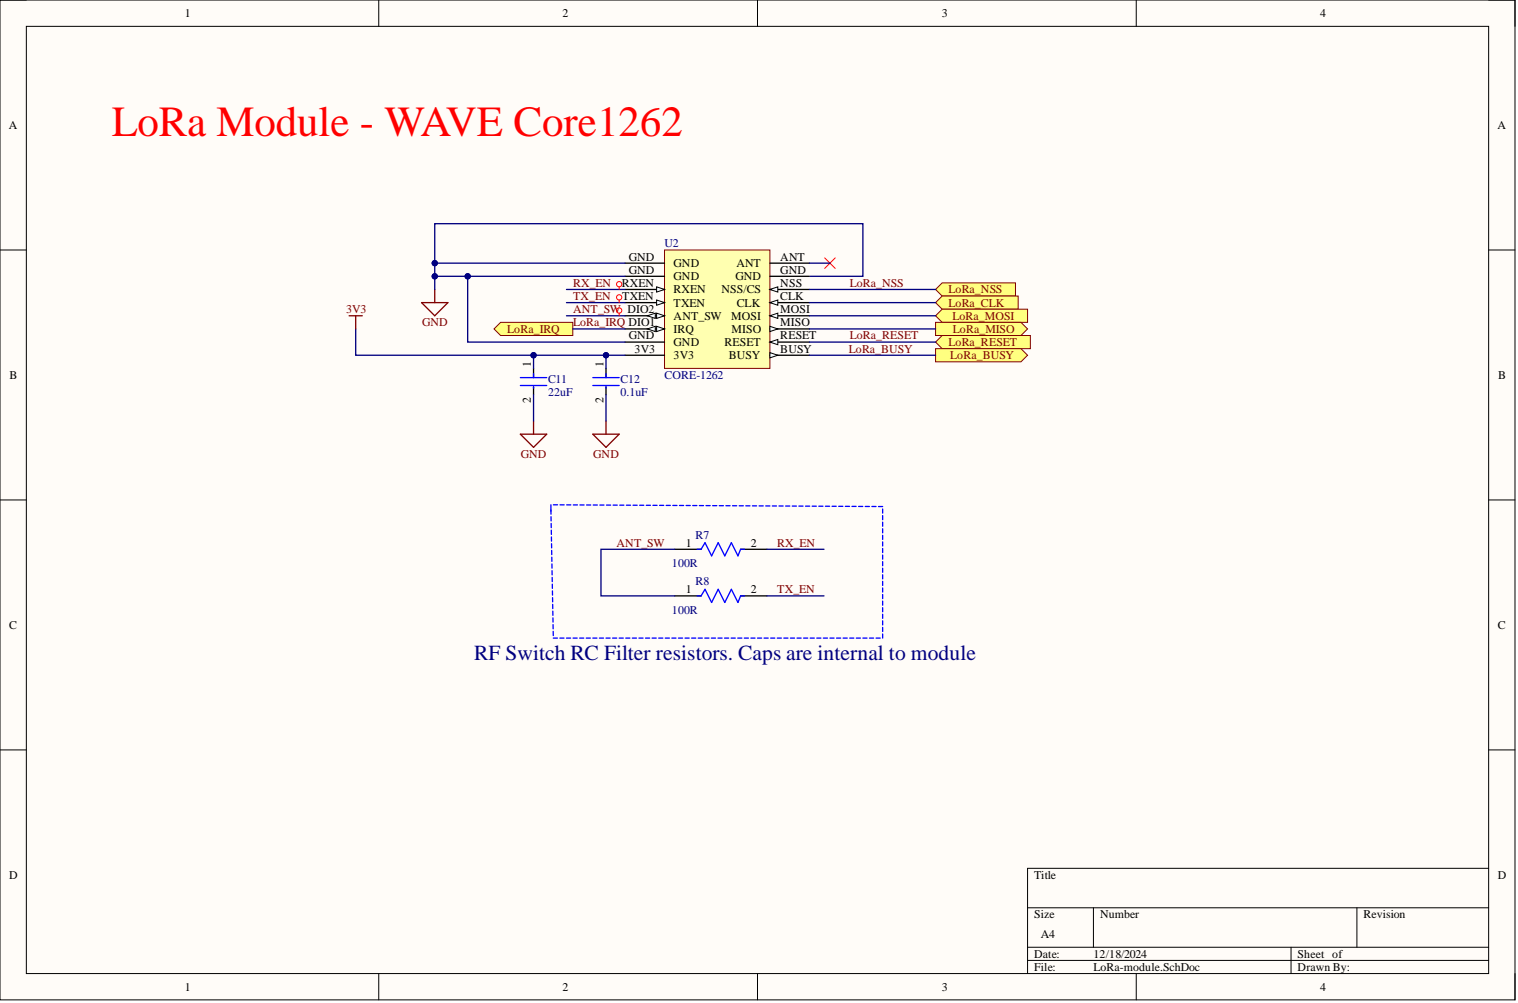
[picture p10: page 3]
Date:; Sheet of; File:; LoRa-module.SchDoc; Drawn By:; GND GND

LoRa Module - WAVE Core1262

GND

RX_EN | | RXEN

TX_EN ANT_SW LoRa_IRQ LoRa_IRQ | | TXEN TXEN ANT_SW DIO2 IRQ DIO1 GND GND

RF Switch RC Filter resistors. Caps are internal to module

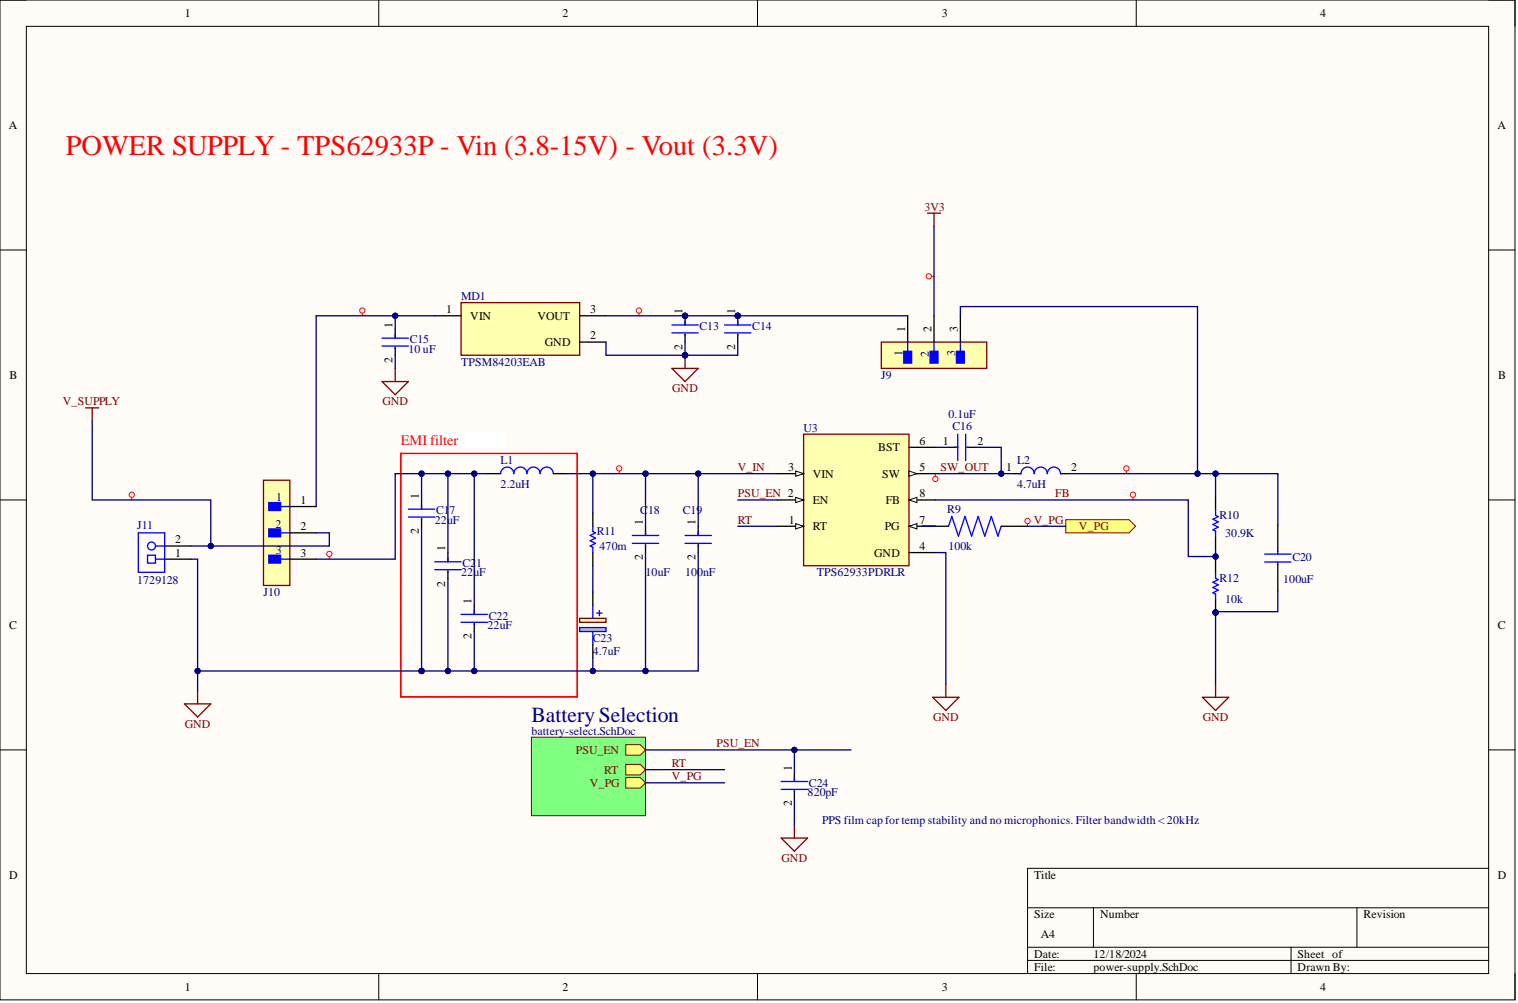
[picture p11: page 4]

POWER SUPPLY - TPS62933P - Vin (3.8-15V) - Vout (3.3V)

Battery Selection battery-select.SchDoc

PPS film cap for temp stability and no microphonics. Filter bandwidth < 20kHz

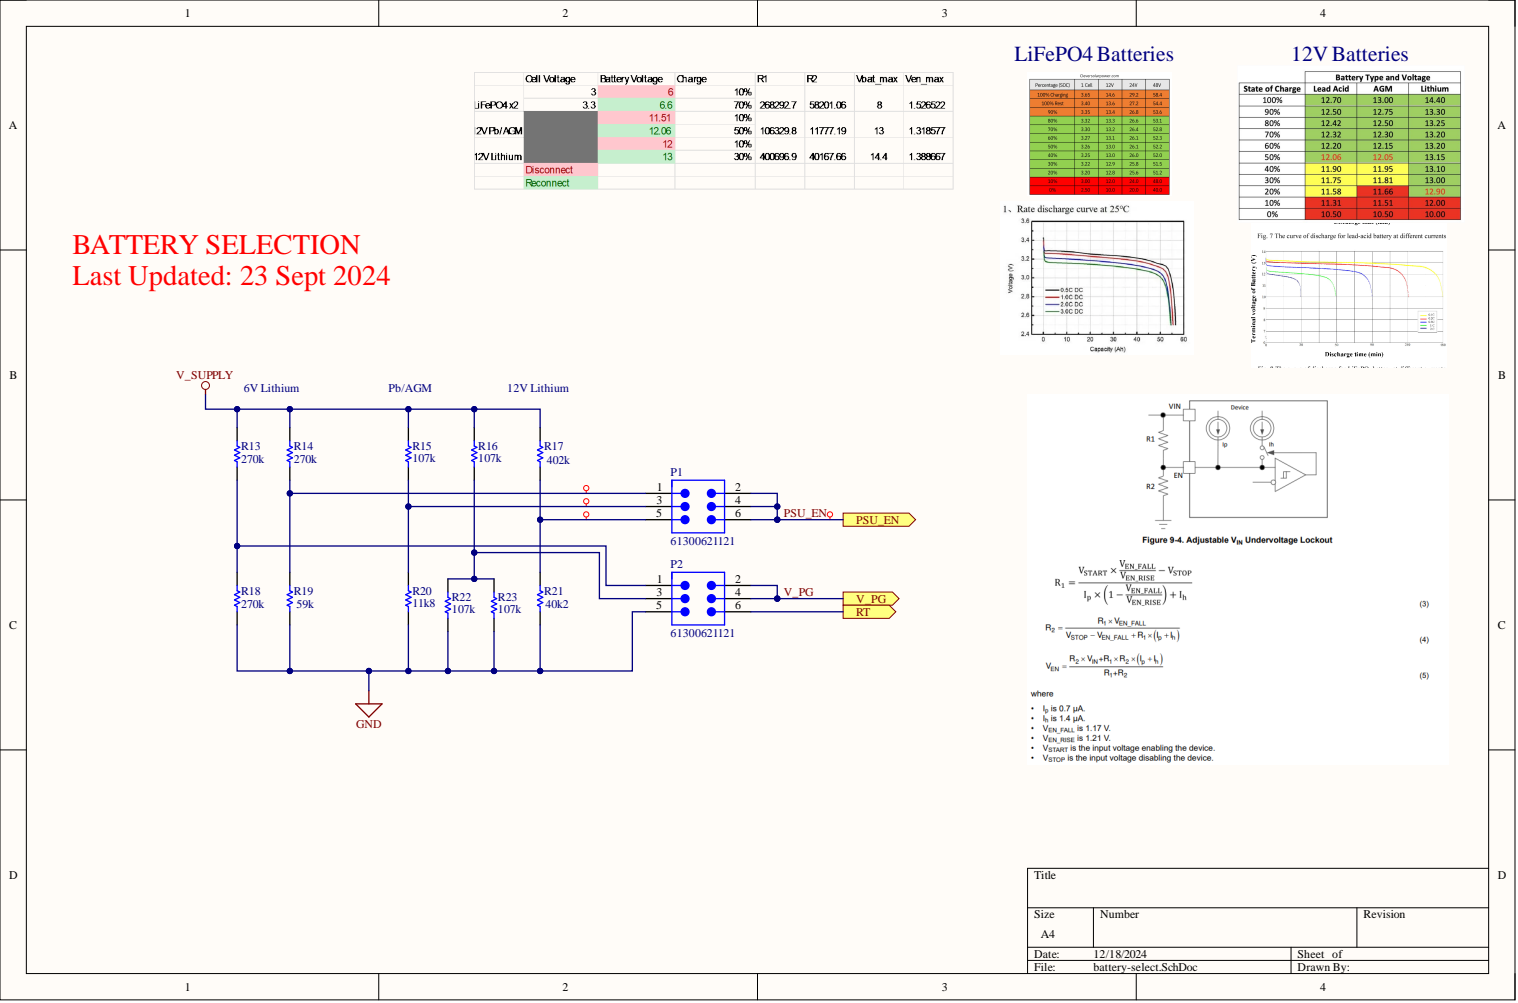
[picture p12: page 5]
Y SELECTION; V Batteries

BATTER
Last Updated: 23 Sept 2024

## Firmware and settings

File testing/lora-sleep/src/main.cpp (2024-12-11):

// SX1262 sleep tester
// Test the functionality of sleeping the esp32 module and waking from a
// recieved messasge fromt he semtech sx1662 module. Press USER_BTN to send a
// packet, The receving node will wake from sleep and blink the LED green three
// times

#include <Arduino.h>
#include <RadioLib.h>
#include <esp_sleep.h>

#define NSS 34
#define IRQ GPIO_NUM_38
#define NRST 48
#define BUSY 33
#define MOSI 35
#define MISO 37
#define SCK 36
#define USER_BTN GPIO_NUM_14

// Set up the RGB LED pins
#define R_PIN 17
#define G_PIN 18
#define B_PIN 16
#define R_CHANNEL 0
#define G_CHANNEL 1
#define B_CHANNEL 2
#define PWM_FREQ 12000
#define PWM_RES 8

#define TRANSMIT_DELAY 1000

SPIClass spi(HSPI);
SPISettings spiSettings(2000000, MSBFIRST, SPI_MODE0);
SX1262 radio = new Module(NSS, IRQ, NRST, BUSY, spi, spiSettings);

// save transmission states between loops
int transmissionState = RADIOLIB_ERR_NONE;

// flag to indicate transmission or reception state
bool transmitFlag = false;

// flag to indicate that a packet was sent or received
volatile bool operationDone = false;

// this function is called when a complete packet
// is transmitted or received by the module
// IMPORTANT: this function MUST be 'void' type
//            and MUST NOT have any arguments!
#if defined(ESP8266) || defined(ESP32)
ICACHE_RAM_ATTR
#endif

void setFlag(void) {
  // we sent or received a packet, set the flag
  operationDone = true;
}

// SX1262 Setup
#define LORA_FREQ 915.0 // MHz
#define LORA_SYNC 0x34  // sync word
#define LORA_POWER 17   // tx power in dBm
#define LORA_PREAMB 16  // # of symbols in preamble
// long fast
#define LORA_BW 250.0 // kHz
#define LORA_SF 11
#define LORA_CR 5

// debounce variables
unsigned long lastDebounceTime = 0;
const unsigned long debounceDelay = 50; // milliseconds
bool buttonState = false;
bool lastButtonState = false;

void sleep();
void ledController(int led_CHANNEL, int brightness, int blinks, int onTime_ms,
                   int offTime_ms);

void setup() {
  Serial.begin(115200);
  spi.begin(SCK, MISO, MOSI, NSS);

  // Setup RGB
  ledcSetup(R_CHANNEL, PWM_FREQ, PWM_RES);
  ledcAttachPin(R_PIN, R_CHANNEL);
  ledcSetup(G_CHANNEL, PWM_FREQ, PWM_RES);
  ledcAttachPin(G_PIN, G_CHANNEL);
  ledcSetup(B_CHANNEL, PWM_FREQ, PWM_RES);
  ledcAttachPin(B_PIN, B_CHANNEL);

  // pinMode(USER_BTN, INPUT_PULLUP);
  // gpio_wakeup_enable(USER_BTN, GPIO_INTR_LOW_LEVEL);

  // initialize SX1262 with default settings
  Serial.print(F("[SX1262] Initializing ... "));
  // gpio_reset_pin((gpio_num_t)IRQ);
  int state =
      radio.begin(LORA_FREQ, LORA_BW, LORA_SF, LORA_CR, LORA_SYNC, LORA_POWER);
  if (state == RADIOLIB_ERR_NONE) {
    Serial.println(F("success!"));
  } else {
    Serial.print(F("failed, code "));
    Serial.println(state);
    while (true) {
      delay(10);
    }
  }

  // set the function that will be called
  // when new packet is received
  // radio.setDio1Action(setFlag);

  // start listening for LoRa packets on this node
  Serial.print(F("[SX1262] Starting to listen ... "));
  state = radio.startReceive();
  if (state == RADIOLIB_ERR_NONE) {
    Serial.println(F("success!"));
  } else {
    Serial.print(F("failed, code "));
    Serial.println(state);
    while (true) {
      delay(10);
    }
  }
}

void loop() {

  sleep();

  // Transmit on button press
  bool reading = digitalRead(USER_BTN) == LOW;
  if (reading != lastButtonState) {
    lastDebounceTime = millis();
  }
  if ((millis() - lastDebounceTime) > debounceDelay) {
    if (reading != buttonState) {
      buttonState = reading;
      if (buttonState) {
        // Send a message
        Serial.print(F("[SX1262] Button pressed! Sending packet ... "));
        uint8_t bytes[] = {'i', 't', 's', ' ', 'c', 'a', 'm', '\0'};
        transmissionState = radio.startTransmit(bytes, 11);
        transmitFlag = true;
      }
    }
  }
  lastButtonState = reading;

  if (operationDone) {
    operationDone = false;
    if (transmitFlag) {
      // the previous operation was transmission, listen for response
      // print the result
      if (transmissionState == 0) {

        // packet was successfully sent
        Serial.println(F("transmission finished!"));
      } else {
        Serial.print(F("failed, code "));
        Serial.println(transmissionState);
      }

      // listen for response
      radio.startReceive();
      transmitFlag = false;
    } else {
      // the previous operation was reception
      // print data and send another packet
      String str;

      int state = radio.readData(str);

      if (state == RADIOLIB_ERR_NONE) {
        // packet was successfully received
        Serial.println(F("[SX1262] Received packet!"));

        // print data of the packet
        Serial.print(F("[SX1262] Data:\t\t"));
        Serial.println(str);

        // print RSSI (Received Signal Strength Indicator)
        Serial.print(F("[SX1262] RSSI:\t\t"));
        Serial.print(radio.getRSSI());
        Serial.println(F(" dBm"));

        // print SNR (Signal-to-Noise Ratio)
        Serial.print(F("[SX1262] SNR:\t\t"));
        Serial.print(radio.getSNR());
        Serial.println(F(" dB"));
      }

      // wait a second before transmitting again
      delay(TRANSMIT_DELAY);

      // send another one
      // Serial.print(F("[SX1262] Sending another packet ... "));
      // uint8_t bytes[] = {0xFF, 0x02, 0x00, 0x00, 'l', 'i',
      //                    'l',  'y',  'g',  'o',  '\0'};
      // transmissionState = radio.startTransmit(bytes, 11);
      transmitFlag = true;
    }
  }
}

void sleep() {
  radio.clearDio1Action();
  pinMode(IRQ, INPUT);
  gpio_wakeup_enable(IRQ, GPIO_INTR_HIGH_LEVEL);
  esp_sleep_enable_gpio_wakeup();
  Serial.println("GOING TO SLEEP");

  esp_light_sleep_start();

  Serial.println("WAKE UP");
  ledController(G_CHANNEL, 80, 3, 400, 250);
  operationDone = true;
  return;
}

void ledController(int led_CHANNEL, int brightness, int blinks, int onTime_ms,
                   int offTime_ms) {
  for (int i = 0; i < blinks; i++) {
    ledcWrite(led_CHANNEL, brightness);
    delay(onTime_ms);
    ledcWrite(led_CHANNEL, 0);
    delay(offTime_ms);
  }
}

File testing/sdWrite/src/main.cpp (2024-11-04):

#include <Arduino.h>
#include <ArduinoJSON.h>
#include <SD.h>

/*
DEBUGGING

Comment out for debugging
*/
#define DEBUG

#ifdef DEBUG
#define SERIAL_BAUD 115200
#define DBG_PRINTLN(MSG) Serial.println(MSG)
#define DBG_PRINT(MSG) Serial.print(MSG)
#else
#define DBG_PRINTLN(MSG)
#endif

#define SD_CS 10   // SD chip select pin
#define SD_SCK 12  // SD sck pin
#define SD_MOSI 11 // SD mosi pin
#define SD_MISO 13 // SD miso

// objects
File file;
JsonDocument doc;

// Function prototypes
String JSONtoSTRING(String json);
void appendHistory(String fileName, String *Message);
void printFileContent(String fileName);

void setup() {
#ifdef DEBUG
  Serial.begin(SERIAL_BAUD);
  delay(1000); // Needed to add delay to give Serial Monitor time to connect,
               // can remove when not debugging
#endif

  SPI.begin(SD_SCK, SD_MISO, SD_MOSI, SD_CS);
  SPI.setDataMode(SPI_MODE0);

  DBG_PRINTLN("~~~~~~~~~~~~~~~~~~~DEGUB start~~~~~~~~~~~~~~~~~~~");

  // Initialize SD card
  if (!SD.begin(SD_CS)) {
    DBG_PRINTLN("Failed to mount SD card!");
    DBG_PRINTLN("");
    return;
  } else {
    DBG_PRINTLN("SD card mounted successfully.");
    DBG_PRINTLN("");
  }

  // create sample JSON object identical to what will recieved from client
  JsonObject history = doc.to<JsonObject>();
  history["payload"] = "Hello World!";
  history["nodeID"] = 5;
  history["SOS"] = 0;
  String mockMessage;
  serializeJson(history, mockMessage);
  DBG_PRINT("Unparsed JSON object: ");
  DBG_PRINTLN(mockMessage);
  DBG_PRINTLN("");
  // Convert JSON to "payload,nodeID,SOS"
  String parsedJSON = JSONtoSTRING(mockMessage);
  // Wrire to a new line in history.csv, pass the address of the parsed string
  appendHistory("/history.csv", &parsedJSON);
  // print out the entire file to serial monito
  printFileContent("/history.csv");
}

void loop() {}

//~~~~~~Function DEFS~~~~~~

String JSONtoSTRING(String json) {
  deserializeJson(doc, json);

  String payload = doc["payload"];
  int nodeID = doc["nodeID"];
  int SOS = doc["SOS"];

  String combinedString =
      "\"" + payload + "\"" + "," + String(nodeID) + "," + String(SOS); // "payload",nodeID,SOS
  DBG_PRINT("Parsed to String: ");
  DBG_PRINTLN(combinedString);
  DBG_PRINTLN("");

  return combinedString;
}

void appendHistory(String fileName, String *message) // "payload", nodeID, SOS
{
  // Write to file
  file = SD.open(fileName, FILE_APPEND);

  if (!file) {
    DBG_PRINTLN("Failed to open file for writing!");
    return;
  } else {
    DBG_PRINTLN("Writing to SD card...");
    DBG_PRINTLN("");
    file.println(*message);
    file.close();
  }
}

void printFileContent(String fileName) {
  file = SD.open(fileName, FILE_READ);
  // buffer to store the file content
  String fileContent = "";
  // stores conetent char by char into the buffer
  while (file.available()) {
    fileContent += (char)file.read();
  }
  // Print the entire buffer
  DBG_PRINT("contents of ");
  DBG_PRINT(fileName);
  DBG_PRINTLN(":");
  DBG_PRINTLN(fileContent);
  file.close();
}

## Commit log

2024-09-04 Add files via upload
    Added reference docs.
    [SX1262MB1CAS_915MHz_e428v03a_BOM.xlsx, SX1262_e428v03a.PcbDoc, SX1262_e428v03a.PcbLib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]
2024-09-04 Working on pin Map, most necessary pins for booting added
    [ESP32 Pin Map.xlsx]
2024-09-05 Update ESP32 Pin Map.xlsx
    [ESP32 Pin Map.xlsx]
2024-09-05 fixed typo
    [ESP32 Pin Map.xlsx]
2024-09-06 Added High Level Block diagram
    [SX1262MB1CAS_915MHz_e428v03a_BOM.xlsx, SX1262_e428v03a.PcbDoc, SX1262_e428v03a.PcbLib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]
2024-09-06 Moved files
    [ESP32 Pin Map.xlsx]
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2024-09-07 Started Hardware doc
    organized document and researched a few components
    [Hardware Overview.xlsx]
2024-09-08 added items
    [Hardware Overview.xlsx]
2024-09-10 C6 PCB footprints
    [ESP32-C6-MINI-1 PCB Footprint.dxf]
2024-09-10 Made part changes
    Changed from C3 to S3
    removed CP2102
    removed USB-Port
    Removed Charge Controller
    [Hardware Overview.xlsx]
2024-09-11 Added items
    Just need to find suitable voltage regulator
    [Hardware Overview.xlsx]
2024-09-13 Update Hardware Overview.xlsx
    [Hardware Overview.xlsx]
2024-09-16 First prep room order
    Created
    - order tracking spreadsheet
    - prep room order template
    - prep room order 1
    [ProjectSuppliesRequestForm_FLoRaCommunications_Order1.xlsx, order-tracking.xlsx, template-ProjectSuppliesRequestForm_FLoRaCommunications_OrderX.xlsx]
2024-09-16 update order 1
    [ProjectSuppliesRequestForm_FLoRaCommunications_Order1.xlsx, ProjectSuppliesRequestForm_FLoRa_Communcations_Order1.xlsx, order-tracking.xlsx]
2024-09-17 Added V. Regulator options
    [Hardware Overview.xlsx]
2024-09-19 renamed to kebab-case
    [ESP32 Pin Map.xlsx, ESP32-C6-MINI-1 PCB Footprint.dxf, Hardware Overview.xlsx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]
2024-09-19 fixed multiple files
    [Hardware Overview.xlsx, esp32-pin-map.xlsx, hardware-overview.xlsx]
2024-09-19 Power supply decision
    [power-supply-decision-matrix.xlsx]
2024-09-21 Added Power Audit
    [Power Audit.xlsx]
2024-09-21 Rename to kebab-case
    [Power Audit.xlsx, power-audit.xlsx]
2024-09-21 added s3 datasheet, moved some files
    [ESP32-C6-MINI-1 PCB Footprint.dxf, SX1262MB1CAS_915MHz_e428v03a_BOM.xlsx, SX1262_e428v03a.PcbDoc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]
2024-09-21 Added
    WEBENCH simulations for the TPS62933 (including load/input transients) for models with emi-filter and without.
2024-09-29 added petal v0.0.0 sch stuff
    [Core1262.SchLib, FLoRa0.0.PrjPcb, FLoRa0.0.SchDoc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]
2024-10-01 working on testing scheme
    [testing-scheme.xlsx]
2024-10-04 file tree management
    moved aux docs into a folder called resources
    [ESP32-C6-MINI-1 PCB Footprint.dxf, ProjectSuppliesRequestForm_FLoRa_Communcations_Order1.xlsx, SX1262MB1CAS_915MHz_e428v03a_BOM.xlsx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]
2024-10-10 moved from git to onedrive while in progress
    [testing-scheme.xlsx]
2024-10-15 Completed hardware testing-scheme
    [testing-scheme.xlsx]
2024-10-15 pcb v0.0 submitted to JLCPCB
    [Core1262.SchLib, FLoRa0.0.PrjPcb, FLoRa0.0.SchDoc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]
2024-10-16 order-tracking
    Updated order tracking with project supplies order 3 and pcb order 1
    [ProjectSuppliesRequestForm_FloraCommuncations_Order1.xlsx, ProjectSuppliesRequestForm_FloraCommunications_Order2.xlsx, ProjectSuppliesRequestForm_FloraCommunic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]
2024-10-18 Received orders from mouser and digikey
    [ProjectSuppliesRequestForm_FloraCommunications_Order3.xlsx, order-tracking.xlsx]
2024-10-22 test plan
    Created test plan from ryans assignment. Moved some files around so it's not garbage anymore
    [ESP32-C6-MINI-1 PCB Footprint.dxf, SX1262MB1CAS_915MHz_e428v03a_BOM.xlsx, SX1262_e428v03a.PcbDoc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]
2024-10-28 created assembly notes for petal v0.0
    [lvd-testing.xlsx, psu-testing.xlsx, testing-scheme.xlsx]
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2024-11-03 Added SD write
    This program takes a JSON object and writes it to a new line of a .csv file
    [history.csv]
2024-11-04 Added new parts order
    [ProjectSuppliesRequestForm_FLoRaCommunications_Order4.xlsx]
2024-11-04 SD Cards
    [ProjectSuppliesRequestForm_FLoRaCommunications_Order4.xlsx]
2024-11-04 tidy up
    [ProjectSuppliesRequestForm_FLoRaCommunications_Order4.xlsx]
2024-11-04 file hygiene
    - Moved ECO folder to flora-docs
    - Updated root readme to reflect changes
    - moved enclosure-v0_0 into petal-v0_0 folder
    - added petal readme
    - added testing readme
    - created testing folder in petal for testing results
    [assembly-checklist.xlsx, initial-checklist.xlsx, lvd-testing.xlsx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]
2024-11-04 enclosure files
    Added enclosure files
    [base.stl, inlay.stl, lid.stl]
2024-11-04 renamed to assmebly checklist
    [assembly-checklist.xlsx]
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2024-11-15 Updated order tracking
    Orders 4 & 5
    [ProjectSuppliesRequestForm_FLoRaCommunications_Order4.xlsx, ProjectSuppliesRequestForm_FloraCommunications_Order5.xlsx, order-tracking.xlsx]
2024-11-15 Update psu-testing.xlsx
    Updated template with new stuff
    [psu-testing.xlsx]
2024-11-29 Added radio testing stuff
    [assembly-checklist.xlsx, filtered_results.csv, results.csv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]
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2024-12-18 Cleaned up pcb design files and added schematic pdf
    [DEPRECATED-lvd.SchDoc, FLoRa0.0.PcbLib, FLoRa0.0.PrjPcb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]
2024-12-18 updated testing readme and test plan version
    [petal-current-measurement.xlsx]
